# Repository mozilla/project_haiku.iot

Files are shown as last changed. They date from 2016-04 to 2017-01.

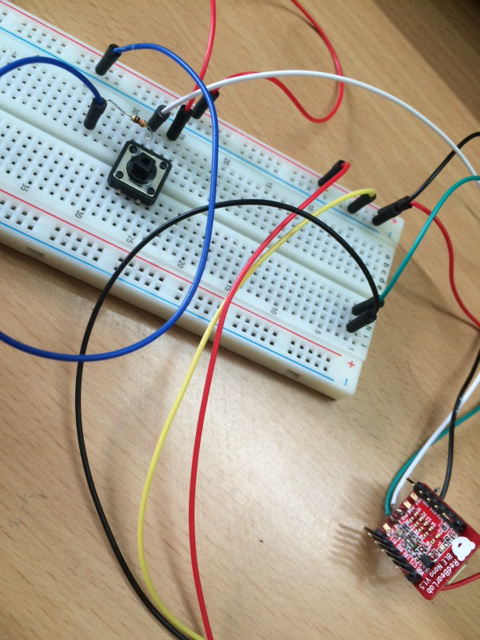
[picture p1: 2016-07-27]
Bluetooth/nRF51822/Arduino/Assets/images/BLE-Peripheral-NeoPixel-Nano-Circuit-2.JPG

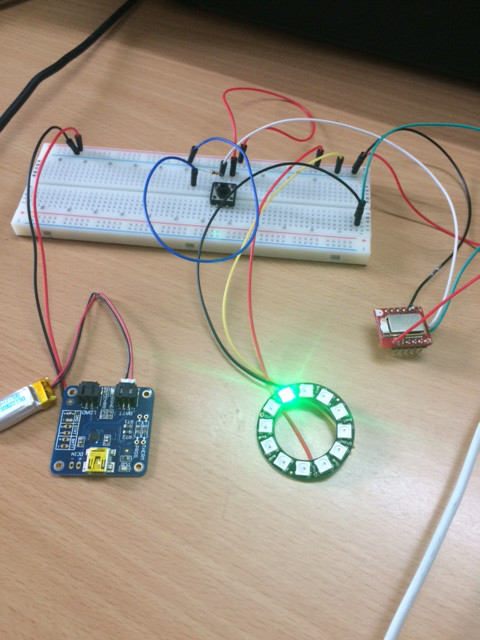
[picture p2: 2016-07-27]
Bluetooth/nRF51822/Arduino/Assets/images/BLE-Peripheral-NeoPixel-Nano-Circuit-3.JPG

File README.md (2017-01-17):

# Mozilla Project Haiku

### &#x1F534; Project Status - On Hold

Learn about the Project Haiku (former Project Smart Home) on the Mozilla wiki
* [https://wiki.mozilla.org/Connected_Devices/Projects/Project_Haiku](https://wiki.mozilla.org/Connected_Devices/Projects/Project_Haiku)

Follow our progress in our Github wiki
* [https://github.com/mozilla/project_haiku.iot/wiki](https://github.com/mozilla/project_haiku.iot/wiki)
* Github won't notify you when this wiki is updated, but you can [subscribe via RSS](https://github.com/mozilla/project_haiku.iot/wiki.atom).

Links to related repos
* The status API service used by Project Haiku and its experiments    
https://github.com/mozilla/project_haiku_status_api.iot    
* Reports and visualizations of data collected from Project Haiku user studies    
https://github.com/mozilla/project_haiku_dataviz.iot    
* Signalling server to connect pairs of WebRTC clients
https://github.com/mozilla/project_haiku_webrtc_signaling.iot

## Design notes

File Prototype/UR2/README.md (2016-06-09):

# smarthome.iot / User Research #2 Prototype

This prototype will support of our next round of user research, in which we are investigating 1:1 communication with a simple physical device, built around the Particle "Photon" board.

> This prototype was built for a specific purpose - to test a hypothesis and prompt feedback to help refine and steer development of products from Project Haiku. Please [contact the team](https://wiki.mozilla.org/Connected_Devices/Projects/Project_Haiku#Getting_in_touch) if you have suggestions or questions, or encounter problems building it.

### Overview

The device connects over Wifi to Particle's cloud service where "messages" are exchanged between an identical "paired" device held by a friend. The device has a single button, and clicking/double-clicking/long-clicking on one results in a different LED animation on the other.

### Bill of Materials

Vendor links are just a suggestion. You may want to adjust based on what you can get hold of locally, quantity etc. Our code is currently specific to the Photon board (but could be ported to other similar platforms.)

* Particle Photon *without headers* [Particle store](https://store.particle.io/)
* USB LiIon/LiPoly charger - [Adafruit](https://www.adafruit.com/products/259)
* "Neopixel" WS2812 addressable LED strip. Non-waterproof, 60 LEDs per meter. (cut strip of 5 LEDs per unit) [Amazon](http://www.amazon.com/Mokungit-Programmable-Individually-Addressable-Non-waterproof/dp/B01D1EDDR8)
* 3.7v 2000mAh Lithium Ion Battery [Adafruit](https://www.adafruit.com/products/2011) - note that shipping restrictions apply. Max 8 per order, no USPS delivery.
* 12x12x7mm Momentary Tactile Push Button Switch 4 Pin DIP [Amazon](http://www.amazon.com/uxcell%C2%AE-12x12x7mm-Momentary-Button-Switch/dp/B009ERT2NQ)
* 10K Ohm 1/4 watt resistor [Adafruit](https://www.adafruit.com/products/2784)
* 33K and 47k resistors for voltage divider [Adafruit](https://www.adafruit.com/products/2786), [Amazon](http://www.amazon.com/Projects-25EP51433K0-33k-Resistors-Pack/dp/B0185FCAUY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)  or [Amazon](http://www.amazon.com/Projects-EPC-106-Value-Resistor-Kit/dp/B00NENE5WY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)
* Pancake vibration motor [Adafruit](https://www.adafruit.com/products/1201)
* Mini USB Cable - A to Mini B [Amazon](http://www.amazon.com/StarTech-com-Mini-USB-Cable-USB2HABM6RA/dp/B004NO0L4O)
* Ribbon wire for all the connections. E.g. [Sparkfun](https://www.sparkfun.com/products/10646)
* Strip Board [Amazon](https://www.amazon.com/gp/product/B0076O73HQ/ref=oh_aui_detailpage_o00_s00?ie=UTF8&psc=1)

Tools
* Soldering Iron [Amazon](https://www.amazon.com/gp/product/B013JM4AW4/ref=oh_aui_detailpage_o08_s01?ie=UTF8&psc=1), Lead Solder [Sparkfun](https://www.sparkfun.com/products/9161) [Optional  [metal stand](https://www.sparkfun.com/products/9477) , [helping hand](http://www.amazon.com/SE-MZ101B-Helping-Magnifying-Glass/dp/B000RB38X8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) ]
* Wire Stripper [Sparkfun](https://www.sparkfun.com/products/12630) , Flush Cutters [Sparkfun](https://www.sparkfun.com/products/11952)
* Hot Glue gun or permanent glue to stick plastic parts
* Enclosure 3d Printed using 3d printer or using vendors such as Shapeways

### Building the Prototype Device

#### 3D Printing the enclosure

The OpenSCAD source file and print-ready [enclosure.stl](assets/3d/enclosure.stl) are in the [Prototype/assets/3d](assets/3d) directory. We used white ABS with a normal "regular quality" print profile: 0.25mm layer height, 1mm shell, no brim or other supports.

#### Assembling the Electronics

Most parts are off the shelf. If creating the device on the breadboard you can simply wire it up with jumper wires. To fit into the enclosure, you will need to cut down a piece of strip board to 6 columns and ~14 rows. The videos below walk through wiring it all up and getting it into the enclosure.

* [Wiring diagram](assets/BlinkyButton_bb.png)
* [Walkthrough video 1/3](https://www.youtube.com/watch?v=C2MHg81-BwQ) - First stage of assembling the device, wiring up the Particle Photon board and the LiPo charging board2.
* [Walkthrough video 2/3](https://youtu.be/lktK18RHnlE) - Completing wiring
* [Walkthrough video 3/3](https://youtu.be/VAnI2gIuZO8) - Packing the enclosure

#### Software

##### Setup Your Photon

* To use Photon board, you need to setup your Photon. Particle provides plenty of options for registering your Photons with your local WiFi.  Recommended way to setup your photon is via [Particle Mobile App](https://docs.particle.io/guide/getting-started/start/photon/#prerequisites-for-setup), you'll have to create a particle account in order to manage your particle boards.
* If you prefer command line tools, you'll need to have [node.js](https://nodejs.org/) and [particle-cli](https://github.com/spark/particle-cli) installed on your computer.
* Follow the [quickstart instruction](https://docs.particle.io/guide/getting-started/start/photon/#step-1-power-on-your-device) on photon website to create an particle account, connect your photon to wifi, and claim it under your account.
* Please note both the devices in a pair should be claimed under the same particle account.

##### Configure

* Go to https://build.particle.io, and click on Create New App and name it e.g. ‘buzzy-pixel’ and hit save icon on left. This should create a new file buzzy-pixel.ino.
* Click on Libraries button, and find BlingButton in Community Libraries. Select BlingButton library, and click on Include In App.
* Go back to your created app ‘buzzy-pixel’, and paste following code inside the buzzy-pixel.ino file.
https://github.com/mozilla/project_haiku.iot/blob/master/Prototype/InternetButton/buzzy-pixel/buzzy-pixel.ino

Note: For accessing included BlingButton library, change include reference in above buzzy-pixel.ino code from "BlingButton.h" -> "BlingButton/BlingButton.h",  "Page.h" -> "BlingButton/Page.h"

* Add new file by clicking on ‘+’ on top right. Rename the file as ‘ButtonConfig.h’ [You can delete the corresponding cpp file created by default]
* Paste the below config settings code in ButtonConfig.h
https://github.com/mozilla/project_haiku.iot/blob/master/Prototype/InternetButton/buzzy-pixel/ButtonConfig.h

###### Understanding ButtonConfig

ButtonConfig file settings are used to identify Device 1 and Device 2 in a pair.
* For Device 1  PUBLISH_EVENT_NAME  should be set as "DEVICE_1_BUTTON_PRESS" and SUBSCRIBE_EVENT_NAME should be "DEVICE_2_BUTTON_PRESS".
* For Device 2 in a pair PUBLISH_EVENT_NAME  should be set as "DEVICE_2_BUTTON_PRESS" and SUBSCRIBE_EVENT_NAME should be set as "DEVICE_1_BUTTON_PRESS.
* BATTERY_CHECK flag in config file is used to trigger [battery level check code](https://github.com/mozilla/smarthome.iot/blob/master/Prototype/InternetButton/buzzy-pixel/buzzy-pixel.ino#L116) . It ensures device goes to sleep if battery level is below the BATTERY_THRESHOLD.
* BATTERY_CHECK_TIME flag sets the time interval after which you want to repeat battery level check.

##### Flash code

Make sure both your photon devices are connected and breathing cyan.  By default ButtonConfig is set for Device1, follow below steps to flash Device 1 in a pair.

* Click on Devices button in https://build.particle.io, and star the device you want to flash.
* Click Verify button, It should compile code in the cloud and you should get code verified message on bottom left
* Click Flash button, if it's blinking purple, and reboot to breathing cyan after a while, it should be working properly.

Update ButtonConfig.h (See Understanding ButtonConfig) for Device 2 and repeat above three steps. After flashing, devices should be communicating and sending ambient messages to paired device.

##### Alternative: Flash with Command Line Tools

Login particle with your email and password if you haven't using command

* particle login.

Make sure you cd into the Prototype/InternetButton/buzzy-pixel directory, change the ButtonConfig.h in Prototype/InternetButton/buzzy-pixel/ButtonConfig.h and flash code with following command:

* particle flash {your_photon_name} ./*

If it's blinking purple, and reboot to breathing cyan after a while, it should be working. Change the ButtonConfig.h for Device 2 settings and flash Device 2.

[Link to End to End instructions >>](https://drive.google.com/a/mozilla.com/file/d/0ByJ_mHuB-es3ckNXVHVpNDFPTUU/view)

### Operating Instructions

#### Connecting to WiFi network

After device is flashed with buzzy-pixel code, you can connect to a different WiFi network (without captive portal) using below steps.

* Make sure your WiFi is turned on. If phone: Tap Home > Settings > WiFi on your phone. If computer: do tap WiFi icon on your computer to choose a WiFi network.
* Press SETUP button on your device for 3 seconds. This will put your device in Listening Mode and your device should begin blinking dark blue. When your device is in Listening Mode, it is waiting for you to connect it to WiFi.
* Go to Home > Settings > Wifi and change to the Photon-XXXX network.
* After connected to Photon-XXXX network, open browser and enter this URL http://192.168.0.1/index.html in a browser window.
* Click the Scan button. A list of WiFi networks will show.
* Press the option button for your home WiFi network.
* Enter your home WiFi password in the Password field. Then click Connect button. Your device should blink green to let you know it’s trying to connect to the internet. An alert will show with help instruction in case you entered wrong password. Press OK.
* Give your device a few seconds to connect and start blinking light blue. When it is blinking light blue, your device is happily connected to the Internet!

#### Reset to remove stored WiFi data from device
To wipe any stored WiFi credentials on the device, hold the MODE button for about ten seconds, until the RGB LED blinks blue rapidly.

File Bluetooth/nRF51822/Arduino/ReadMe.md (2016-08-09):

# Bluetooth Low Energy (BLE) technology

Arduino sketches to flash on RedBear Labs nRF51822 or BLE Nano board. Install Lightblue iOS app or the Android App - B-BLE to scan and debug BLE peripheral devices

## Steps to run BLE_UART_LED

* Follow Get Started steps using link below and Install latest 1.0.6 RedBearLabs nRF51822 board using board manager: https://github.com/RedBearLab/nRF51822-Arduino#install-board-package-add-on

* To upload the code on BLE Nano or nRF51822 dev board there are two options
* Option 1: Use Arduino IDE to compile and upload the code on the respective boards

* Option 2: The bootloader allows you to load firmware Over-the-air, for example, if you do not have the MK20 USB interface dongle.
 https://github.com/RedBearLab/nRF51822-Arduino#ota

a) Export Compiled library using Menu -> Sketch -> Export Compiled Binary

b) Install Nordic "nRF Toolbox” App on your smart phone and use it to open compiled library sent to your phone using air drop. Select file type "application" and select a device (you should see DFU_S130_V1.0 or RGB [device local name set in the sketch] in the device list) , On iOS, select firmware by navigating to User -> Inbox -> select firmware hex file and than click Upload

c) The firmware should upload and should show progress bar of file getting uploaded with the success message if file uploads successfully.

* To run BLE_UART_LED, use LightBlue app to find BLE Nano peripheral ‘RGB’ and select to connect. It should show two services click on write. Select Write new value and enter ‘000000’ for turning LED off. Enter ‘010203’ or any number other than 0 to turn LED on. The lED is attached to pin 13, on BLE Nano its next to 'RedBearLab' text on the board.  You can see the output in serial monitor at baud rate 9600.  

### Arduino Upload Instructions if nothing else work:
For uploading Arduino sketches your board should be preloaded with boot loader.hex. Ideally the above steps should work without explicit manual copy of the bootloader.hex.

In case you are getting error uploading Arduino file on the board, you can try copying bootloader.hex to /MBED
https://github.com/RedBearLab/nRF51822-Arduino#burn-bootloader

For Mac, I had to copy using Terminal  cp -vX bootloader.hex /Volumes/MBED/

## Steps to run BLE-Peripheral-SPI-LED

* Install 1.0.5 RedBearLabs nRF51822 board using board manager: https://github.com/RedBearLab/nRF51822-Arduino#install-board-package-add-on . There is an issue because of which code doesn't compile using latest 1.0.6 board. See https://github.com/sandeepmistry/arduino-BLEPeripheral/issues/70

* Open BLE-Peripheral-SPI-LED.ino file and upload the code to the respective board

* To run  BLE-Peripheral-SPI-LED, use LightBlue app to find BLE Nano peripheral ‘Arduino’ or 'LED' and select to connect. It should show one READWRITE service. Select Write new value and enter ‘00’ for turning LED off. Enter ‘01’ or any number other than 00 to turn LED on. You can see the output in serial monitor at baud rate 9600.  

### OTA Application upload

* Click Sketch -> Export Compiled Library. This will compile and create hex file in the same folder as respective ino file

* Send the hex file using Airdrop to SmartPhone and use nRFToolBox app to open the hex file

* Select the file in the app and the device to upload file to. Press reset button on the board and click upload in the app. Everytime, if you reset the board by hitting the button on the board, the bootloader will broacast the OTA service via BLE for 5 sec waiting for a connection to be made. Otherwise, it will start the pre-loaded firmware.

[Link to Video](http://youtu.be/w5vUd6isJYQ) to update RBL nRF51822 OTA and and run BLE-Peripheral-SPI-LED

## Steps to run BLE-Peripheral-NeoPixel

* Install 1.0.5 RedBearLabs nRF51822 board using board manager: https://github.com/RedBearLab/nRF51822-Arduino#install-board-package-add-on.

* Go to Sketch -> Include Library -> Manage Libraries. Search for Adafruit NeoPixel and install latest version 1.0.5. Installed library needs nRF51 board support to compile.
See https://github.com/adafruit/Adafruit_NeoPixel/pull/42

* Overwrite Adafruit_NeoPixel.cpp inside installed libraries at /Documents/Arduino/libraries/Adafruit_NeoPixel/ with [nRF51 Adafruit_Neopixel.cpp](https://github.com/mozilla/project_haiku.iot/tree/master/Bluetooth/nRF51822/Libraries/Adafruit_NeoPixel_nRF51/) file from here.

* Open BLE-Peripheral-NeoPixel.ino file and upload the code to the respective board.

* To run  BLE-Peripheral-SPI-LED, use LightBlue app to find BLE Nano peripheral device ‘Arduino’  and select to connect. It should show  READ-WRITE and  READ-NOTIFY services. Select READ-WRITE service and click on Write new value and enter ‘00’ for turning NeoPixel off. Enter ‘01’ or any number other than 00 to turn NeoPixel on. You can see the output in serial monitor at baud rate 9600.  Click on READ-NOTIFY service and start listening to notifications. Button press should send 0x01 and turn NeoPixel on. Release of button should send 0x00 and turn NeoPixel off.

[Link to Video](http://youtu.be/LVIa5FvAGQE) to run BLE-Peripheral-NeoPixel on BLE Nano

### Bill Of Material - BLE-Peripheral-NeoPixel

*  BLE Nano & MK20 USB Board - http://redbearlab.com/blenano/
* [Optional] RedBearLab nRF51822 Pinout - http://redbearlab.com/redbearlab-nrf51822/ (Ideally BLE Nano should suffice, for beginners nRF51822 dev board is recommended instead of BLENano at first as it has easy pin out interface)
* "Neopixel" WS2812 addressable LED strip. Non-waterproof, 60 LEDs per meter. (cut strip of 5 LEDs per unit) [Amazon](https://www.amazon.com/Mokungit-Programmable-Individually-Addressable-Non-waterproof/dp/B01D1EDDR8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)
* Sparkfun inventor kits part for resistor, buttons, led and jumper wires - [Sparkfun](https://www.sparkfun.com/products/13110)
* Breadboard - [Sparkfun](https://www.sparkfun.com/products/12002)

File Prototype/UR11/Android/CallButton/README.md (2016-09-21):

# Project Haiku - UR #11

#### Android Call Button app

A simple app that let user call a pre-configured contact on click of button. To simplify testing enter the phone number in the text box provided and click Call. 

Call Button app supports Android 5.0 and above. Tested install with Android Studio 2.1.3

Useful link
* [Creating Android App](https://developer.android.com/training/basics/firstapp/creating-project.html)
* [Requesting permission in Android 6.0 (API level 23 and above)](https://developer.android.com/training/permissions/requesting.html)

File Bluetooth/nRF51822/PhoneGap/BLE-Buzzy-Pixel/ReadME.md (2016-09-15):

# Cordova Android app BluetoothLE Buzzy Pixel

Cordova app communicating with NeoPixel using BLE

## Steps to run BluetoothLE Buzzy Pixel Android app

Follow below commands to create cordova Android app. [Link with command details](https://cordova.apache.org/docs/en/latest/guide/cli/)

* sudo npm install -g cordova
* install android studio which brings in android sdk http://developer.android.com/sdk/installing/index.html?pkg=studio

* cd BLE-Buzzy-Pixel/
* cordova platform add android
* To check if you satisfy requirements for building the platform use command - cordova requirements
* cordova plugin add cordova-plugin-bluetoothle@3.1.0 - [Tested with 3.1.0]
* cordova plugin add path to local cordova-plugin-fetch directory [../Plugins/cordove-plugin-fetch]
* Update [config settings here](https://github.com/mozilla/project_haiku.iot/blob/master/Bluetooth/nRF51822/PhoneGap/BLE-Buzzy-Pixel/www/js/config.js). Read below for more details about variables defined inside config.js.
* Status Service is link to cloud service to read and update status and messages. If you have the URL to cloud service, update config or read below for starting status API service on your local machine.
* cordova build
* connect android device to your machine, then to run app use command- cordova run android

## Config.js
* selfLED is the neopixel assigned to display status of the  BLE device. This value should be same as SELF_LED defined in the [BLENano sketch config](https://github.com/mozilla/project_haiku.iot/blob/master/Bluetooth/nRF51822/Arduino/BLE-Buzzy-Pixel/config.h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)
* baseURL is the address where cloudservice is running
* selfURL is the path '/user/[selfLED]/status' to get client status from cloud service
* ledLength is number of leds on the BLE device
* statusItems is array of relative path to retrieve status of all leds on the BLE device

## Status API Service
* To run status API service on your local, get code from repo https://github.com/mozilla/project_haiku_status_api.iot/tree/exp4-noslots
* Run npm start to start service at port 3000
* Open test client http://localhost:3000/example.html to view and change client 0 status. Click on start button to start polling. Click on first LED toggles status from 1 to 0 (green to red).

## Useful links
* https://cordova.apache.org/docs/en/latest/guide/cli/
* https://github.com/randdusing/cordova-plugin-bluetoothle
* https://www.uuidgenerator.net/
* To remove a plugin cordova plugin remove <plugin-name>
* To view plugin installed - cordova plugin list

## Android version < 6.0

cordova-plugin-bluetoothle 3.1.0 and above needs Andoid API > 23 that comes with Android 6.0 and above.

For version below Android 6, App need to support cordova-plugin-bluetoothle version 2.4.0 or below - TBD

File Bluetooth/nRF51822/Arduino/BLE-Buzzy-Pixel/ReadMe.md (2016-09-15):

# Bluetooth Low Energy (BLE) Buzzy Pixel

BLE Buzzy Pixel Arduino sketch to read and set status and animations on NeoPixel strip

## Steps to run BLE-Buzzy-Pixel

* Install 1.0.5 RedBearLabs nRF51822 board using board manager: https://github.com/RedBearLab/nRF51822-Arduino#install-board-package-add-on.

* Go to Sketch -> Include Library -> Manage Libraries. Search for BLE Peripheral and install version 0.2.0

* Search for Adafruit NeoPixel library and install version 1.0.5. Installed library needs nRF51 board support to compile.
See https://github.com/adafruit/Adafruit_NeoPixel/pull/42

* Overwrite Adafruit_NeoPixel.cpp inside installed libraries at /Documents/Arduino/libraries/Adafruit_NeoPixel/ with [nRF51 Adafruit_Neopixel.cpp](https://github.com/mozilla/project_haiku.iot/tree/master/Bluetooth/nRF51822/Libraries/Adafruit_NeoPixel_nRF51/) file from here.

* Open BLE-Buzzy-Pixel.ino file. Update config.h with pin out and pixel count settings as per your circuit and upload the code to BLE Nano.

* If there are erros while uploading sketch using Arduino IDE, follow [instrcutions here](https://github.com/mozilla/project_haiku.iot/tree/master/Bluetooth/nRF51822/Arduino/Examples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) to copy latest bootloader.hex to BLE Nano board. 

* To test uploadeded sketch BLE-Buzzy-Pixel, use LightBlue iOS app or nRFCOnnect Android app to find BLE Nano peripheral device 'BLE-Buzzy-Pixel'  and select to connect. It should show  READ-WRITE and  READ-NOTIFY services. Select READ-WRITE service and click on Write new value and enter ‘00’ for turning NeoPixel off. Enter ‘01’ to turn NeoPixel on. You can see the output in serial monitor at baud rate 9600.
Click on READ-NOTIFY service and start listening to notifications. Button press should send 0x01 and turn NeoPixel on. Release of button should send 0x00 and turn NeoPixel off.

* To test uploaded sketch with BLE-Buzzy-Pixel Cordova app, install app on Android phone following [instructions here](https://github.com/mozilla/project_haiku.iot/tree/master/Bluetooth/nRF51822/PhoneGap/BLE-Buzzy-Pixel)

[Link to Video](http://youtu.be/B1qS--DboT4) showing BLE-Buzzy-Pixel Cordova app communicating with BLE Nano

### Bill Of Material - BLE-Buzzy-Pixel

*  BLE Nano & MK20 USB Board - http://redbearlab.com/blenano/
* [Optional] RedBearLab nRF51822 Pinout - http://redbearlab.com/redbearlab-nrf51822/ (Ideally BLE Nano should suffice, for beginners nRF51822 dev board is recommended instead of BLENano at first as it has easy pin out interface)
* "Neopixel" WS2812 addressable LED strip. Non-waterproof, 60 LEDs per meter. (cut strip of 5 LEDs per unit) [Amazon](https://www.amazon.com/Mokungit-Programmable-Individually-Addressable-Non-waterproof/dp/B01D1EDDR8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)
* Sparkfun inventor kits part for resistor, buttons, led and jumper wires - [Sparkfun](https://www.sparkfun.com/products/13110)
* Breadboard - [Sparkfun](https://www.sparkfun.com/products/12002)

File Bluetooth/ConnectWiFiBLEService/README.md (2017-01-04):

BLE server that broadcasts WiFi connect service on ARM linux device (BeagleBoneGreen Wireless).
Device can be configured and connect to WiFi by passing WiFi credential
using client app such as nRFConnect (Android).

## Setup BBGW

* [Follow steps](https://github.com/mozilla/project_haiku.iot/wiki/Boot--BeagleBone-Black-via-microSD-Card) to boot BBGW via microSD Card.
Used latest debian image bone-debian-8.6-lxqt-4gb-armhf-2016-11-06-4gb.img.xz 

* Connect BBGW to wifi using connmanctl, type connmanctl.

* First turn tethering off for wifi! 

    _connmanctl> tether wifi off_

    _Disabled tethering for wifi_

* You can then perform the rest of the connmanctl actions to set wifi:

    _connmanctl> scan wifi_

    _Scan completed for wifi_

    _connmanctl> services_

    _TEST wifi_deadbeef0000_4b41595a4545505550_managed_psk_

    _connmanctl> agent on_

    _Agent registered_

    _connmanctl> connect wifi_deadbeef0000_4b41595a4545505550_managed_psk_

    _Agent RequestInput wifi_deadbeef0000_4b41595a4545505550_managed_psk_

    _Passphrase = [ Type=psk, Requirement=mandatory, Alternates=[WPS ] ]_

    _WPS = [ Type=wpspin, Requirement=alternate ]_

    _Passphrase? WTGD3g3gk69lw_

    _Connected wifi_deadbeef0000_4b41595a4545505550_managed_psk_

    _connmanctl> quit_

* Once its connected to WiFi, install and update packages. This takes 15-30 minutes

    _sudo apt-get update_

    _sudo apt-get dist-upgrade_

* Update node to latest version using below commands

    _curl -sL https://deb.nodesource.com/setup_7.x | sudo -E bash -_

    _sudo apt-get install -y nodejs_

## To run [bleno module](https://github.com/sandeepmistry/bleno) on debian

* Install all prerequisite from bleno github page for debian

    _sudo apt-get install bluetooth bluez libbluetooth-dev libudev-dev_

* Run _sudo bb-wl18xx-bluetooth_

    This is built-in script for wireless-capable BeagleBone models
that discovers Bluetooth hardware and sets it up for use.

* Verify if bluetoothhd is running using command

    _pgrep bluetoothd_

    If yes disable the process by using below commands as it
interferes with the [bluetooth process](https://github.com/sandeepmistry/bleno#linux). /user/lib/bluetooth/bluetoothhd deamon shouldn’t appear in process list

    _ps -ef | grep blue_

    _sudo kill -9 <pid>_

## Disconnect WiFi 
* If BBGW is previously connected to WiFi, one can remove stored network name and passphrase by editing file  /var/lib/connman/*/settings
* Reboot BBGW to disconnect from previously connected WiFi

## Run ConnectWiFi BLEService

    npm install

    npm install async@0.6.0 // To fix async.retry error thrown by connman-simplified node package

    node connect.js

## Bluetooth logs using hcidump

    sudo apt-get install bluez-hcidump

    sudo hcidump -t -x

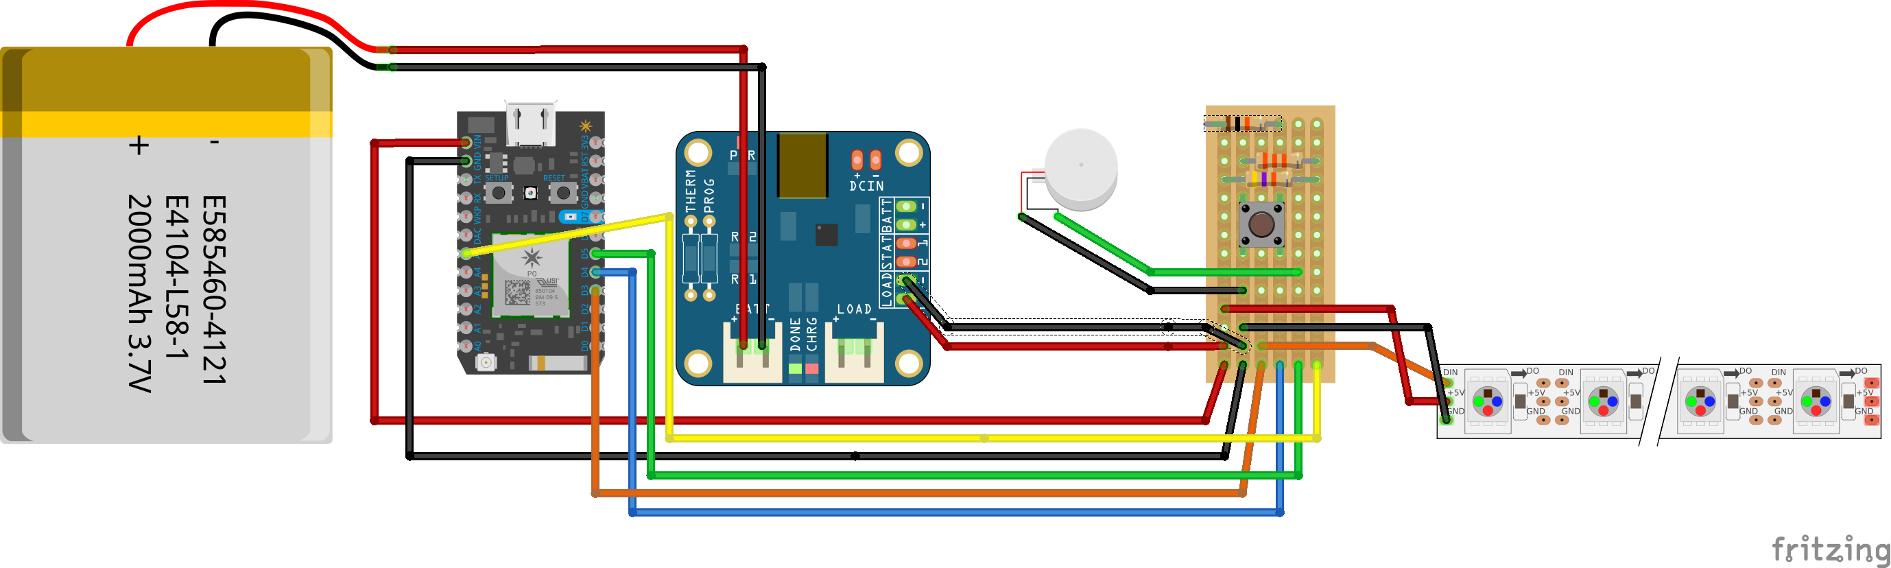
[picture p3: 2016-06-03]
Prototype/UR2/assets/BlinkyButton_bb.png

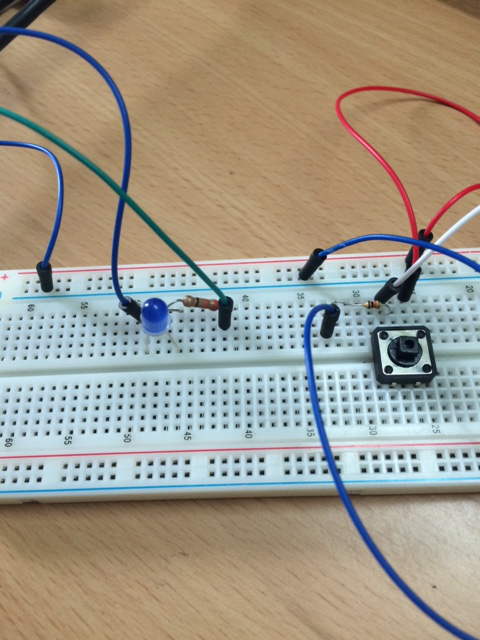
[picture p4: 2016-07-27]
Bluetooth/nRF51822/Arduino/Assets/images/BLE-Peripheral-SPI-LED-Circuit.JPG

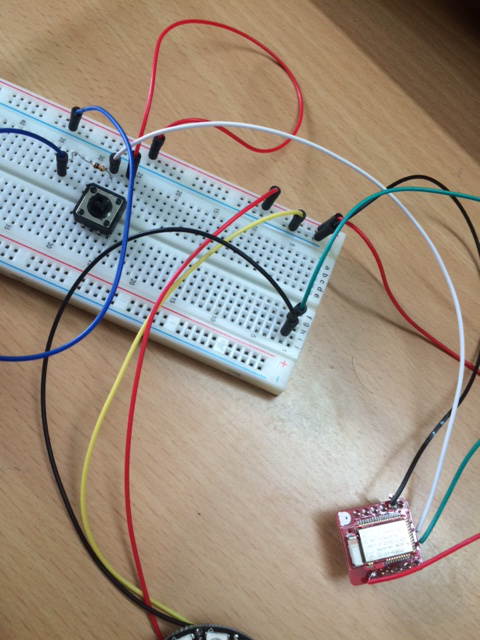
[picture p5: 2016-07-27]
Bluetooth/nRF51822/Arduino/Assets/images/BLE-Peripheral-NeoPixel-Nano-Circuit-1.JPG

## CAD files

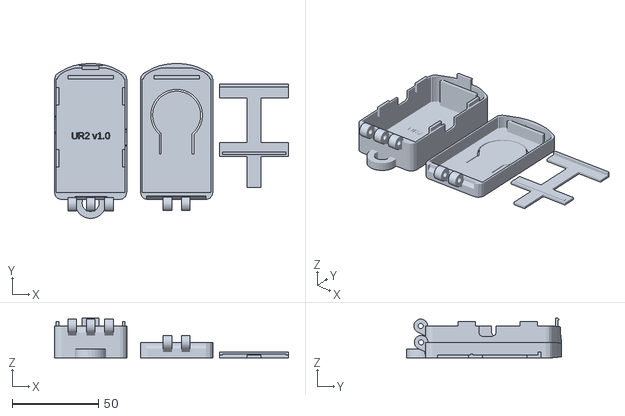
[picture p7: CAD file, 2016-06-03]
Prototype/UR2/assets/3d/enclosure.stl
136.0 x 90.0 x 23.0

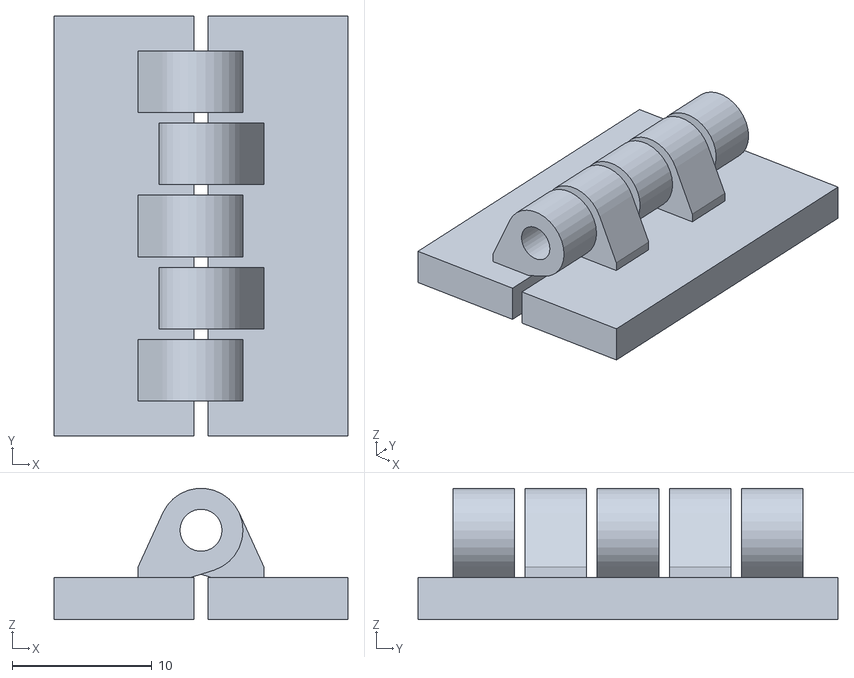
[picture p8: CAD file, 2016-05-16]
Prototype/UR2/assets/3d/test-hinge.stl
21.0 x 30.0 x 9.36

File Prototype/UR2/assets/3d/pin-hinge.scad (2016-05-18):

module example_hinge() {
    translate([0,0,6]) {
        horizontal_pin_with_5_fingers(25, 3);
        translate([5.5,0,-0.5*(6+2.25)]) #cube([10, 30, 3], center=true);
        translate([-5.5,0,-0.5*(6+2.25)]) cube([10, 30, 3], center=true);
    }
}

function debugprint(s) = search(s, []);

module chamfered_cube(dims, chamfer, center=true) {
    w=dims[0]; l=dims[1]; h=dims[2];
    linear_extrude(height=h,twist=0,center=center) {
        offset(r=chamfer) {
          square([w-chamfer*2,l-chamfer*2], center=center);
        }
    }
}

module countersink_ends(h, radius, pin_radius) {
    union() {
        chamfer = pin_radius*1.5;
        // chamfer the pin hole at each end
        translate([0,0,pin_radius/2]) #cylinder(r1=chamfer, r2=pin_radius, h=pin_radius, center=true);
        translate([0,0,h-pin_radius/2]) #cylinder(r1=pin_radius, r2=chamfer, h=pin_radius, center=true);
    }
}

module pin_hinge_unit(h, radius, pin_radius=1.5, index=0, gap=0.5) {
    $fn=30;
    translate([0,radius-gap,0]) difference() {
        // the barrel+lug
        hull() {
            cylinder(r=radius, h=h, center=true);
            translate([index%2>0 ? radius*0.875 : radius*-0.875, radius/2+gap*2, 0]) {
                cube([radius+gap,gap,h], center=true);
            }
        }
        // the hole for the pin
        #cylinder(r=pin_radius, h=h, center=true);
    }
}


module pin_hinge(h, radius, fingers=3, pin_radius=1.5, gap=0.5) {
    total_gap=(fingers-1)*gap;
    unit_h=(h-total_gap)/fingers;
    translate([0,0,unit_h/2]) union() {
        for(i=[0:fingers-1]) {
            translate([0,0, gap*i+i*unit_h]) pin_hinge_unit(unit_h, radius, pin_radius, i);
        }
    }
}

module horizontal_pin_with_5_fingers(length, radius=3, pin_r=1) {
    translate([0,-length/2,3]) rotate([-90,0,0]) pin_hinge(length, radius, 5);
}

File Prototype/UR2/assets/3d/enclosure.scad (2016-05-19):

use <pin-hinge.scad>;
model_version="UR2 v1.0";
width=40;
half_w=width/2;
length=66;
half_l=length/2;
height=17.5;
lid_height=8;
wall=1;
radius_xy=wall*4;
radius_z=wall*2;
inset=0.75;
strap_height=13;

// debug: check all objects sit on the bed platform
//projection(cut=true) {
translate([width/3,0,-1]) %cube([width*4, length+20, 2], center=true);
union() {
    offset_x=5;
    enclosure_base([-1*(width/2+offset_x),0,height/2+wall/2]);
    enclosure_lid([width/2+offset_x,0,lid_height/2+wall/2]);
    enclosure_straps([width+offset_x*2+20,0,0.75]);
}
//}

// the base
module enclosure_base(offsets) {
    translate(offsets) {
        difference() {
            union() {
                hinged_box(width, length, height, 1);
                // lanyard attach point
                translate([0,-0.5*length-6, -0.5*(height+wall)+2.5]) {
                    difference() {
                        cylinder(r=9, h=5, center=true);
                        union() {
                            cylinder(r=5, h=5, center=true);
                            translate([0, 8.5, 0]) cube([18, 5, 5], center=true);
                        }
                    }
                }
                // lip
                union() {
                    lip_w=wall*1.5;
                    lip_h=6;
                    translate([half_w-lip_w/2,-half_l+20,wall+height/2-1]) cube([lip_w, 10, lip_h], center=true);
                    translate([-half_w+lip_w/2,-half_l+20,wall+height/2-1]) cube([lip_w, 10, lip_h], [0,2,0], center=true);
                    translate([half_w-lip_w/2,-half_l+56,wall+height/2-1]) cube([lip_w, 10, lip_h], center=true);
                    translate([-half_w+lip_w/2,-half_l+56,wall+height/2-1]) cube([lip_w, 10, lip_h], center=true);
                }
            }
            union() {
                // version stamp
                translate([0,0,-height/2+wall-0/0.25]) {
                    #linear_extrude(height=1, center=true)
                        text(model_version, size=4, valign="center", halign="center");
                }
                
                // aperture for the usb port
                translate([-width/2-wall, -length/2+39.5, height/2-1]) {
                   rotate(90) charge_port(10, 7, wall*2);
                }
                *translate([width/2+wall-1, -length/2+32, height/2-5]) {
                   #cube(5);
                }
                // aperture for the battery port
                translate([width/2+wall-1, -length/2+32, height/2-1]) {
                   rotate(90) #charge_port(10, 7, wall*2);
                }
                // latch push
                translate([0, length/2+width/4-1.25, width/4-2]) rotate([90,0,0]) #cylinder(r=7, h=inset*2, center=true);
            }
        }
    }
}

// the lid
module enclosure_lid(offsets) {
    translate(offsets) rotate([0,180,0]) {
        difference() {
            union() {
                hinged_box(width, length, lid_height, -1);
            }
            #translate([0,12,lid_height/2]) rotate(180) button(10,36,wall*2);
        }

    }
}

module enclosure_straps(offsets) {
    // the strap
    length=60;
    translate(offsets) {
        union() {
            translate([0,0,0]) cube([8, length, 1.5], center=true);
            #translate([0,-length/2+20,0.75]) cube([width-3, 1.5, 1.5], center=true);
            translate([0,-length/2+22,0]) cube([width, 8, 1.5], center=true);
            translate([0,length/2-4,0]) cube([width, 8, 1.5], center=true);
            translate([0,length/2-0.75,1]) cube([width, 1.5, 3], center=true);
        }
    }
}

module retainer(dims, center=false) {
    xdim=dims[0];
    ydim=dims[1];
    zdim=dims[2];
    half_z=zdim/2;
    translate([0, 0, center? half_z/2 : 0]) {
        cube([xdim, ydim, half_z], center=center);
        translate([0,0,half_z]) {
            if (center) {
                cube([xdim-zdim*2, ydim, half_z], center=center);
            }
            else {
                translate([zdim, 0, half_z]) cube([xdim-zdim*2, ydim, half_z], center=center);
            }
        }
    }

}

module outer_ridges(radius, length, bounds) {
    translate([-1*(bounds[0]/2+radius/2), 0]) {
        rotate([180,0,0]) ridge(radius, length, 1);
    }
    translate([bounds[0]/2+radius/2, 0]) {
        rotate([180,0,0]) ridge(radius, length, -1);
    }
}
module ridge(radius, length, orient=1) {
    rotate([0,0,orient<0?0:180])
    translate([-radius/2, 0, radius/2]) difference() {
        rotate([90,0,0]) cylinder(r=radius, h=length, center=true, $fn=12);
        union() {
            translate([0,0,radius/2]) cube([radius*2, length, radius], center=true);
            translate([-radius/2,0,0]) cube([radius, length, radius*2], center=true);
        }
    }
}

module hinged_oval_box(width, length, height, orient) {
    // WIP/not in use
    hull() {
        translate([0, -length/2+5, 2]) {
            resize(newsize=[width, width/2, height]) sphere(d=width, center=true);
        }
        translate([0, +length/2-5, 2]) {
            resize(newsize=[width*1.25, width/2, height]) sphere(d=width, center=true);
        }
    }
}
module hinged_box(width, length, height, orient) {
    hinge_radius=4;
    hinge_y_offset=length/2+radius_xy+hinge_radius/2;
    difference() {
        union() {
            difference() {
                shell(width, length, height, orient);
                translate([0, -1*hinge_y_offset, orient*(height/2)]) {
                  rotate(a=[0,90,0]) translate([0,0,0.25]) {
                        // add clearance for opposite hinge barrels
                      #cylinder(r=hinge_radius,
                                h=width*.66+orient*-hinge_radius*2,
                                center=true);
                  }
                }

            }
            translate([0, -1*hinge_y_offset, orient*(height/2)]) {
              rotate(a=[90,180,0]) translate([0,0,0.25]) {
                  _pin_hinge(width*.66, hinge_radius, orient>0?0:1);
              }
            }
            // the latch
            translate([0,length/2+8.5,orient*(height/2-3)]) {
                translate([0,-1.5,0]) cube([20, wall, 6], center=true);
            }
            if (orient > 0) {
                translate([0,length/2+7.25,height/2+4.5]) {
                    translate([0,-1,-4.5]) cube([10, wall*1.5, 10], center=true);
                    rotate([90, 90, 0]) ridge(1, 10, 1);
                }
            }
        }
        union() {
            if (orient < 0) {
                // lid latch receiver
                translate([0,length/2+7.25,height/2-3]) {
                    difference() {
                        translate([0,0,-1.5]) #cube([10, wall*1.5, 2], center=true);
                        *translate([0,-1,-4.5]) cube([10, wall*1.5, 10], center=true);
                    }
                }
            }
        }
    }
}

module _pin_hinge(h, radius, is_top=0, clearance=0) {
    fingers=5;
    pin_radius=1.5;
    gap=0.25;
    total_gap=(fingers-1)*gap;
    unit_h=(h-total_gap)/fingers;
    rotate([-90,0,0]) rotate([0,90,0]) translate([0,-radius,-1*(h/2)+unit_h/2]) {
        for(i=[0:fingers-1]) {
            if (i%2>0 && is_top) {
                translate([-0.5,0, gap*i+i*unit_h]) {
                    pin_hinge_unit(unit_h, radius, pin_radius, i, gap);
                    translate([radius,radius*2,0]) cube([radius*1.5, radius, unit_h], center=true);
                }
            }
            if (i%2==0 && !is_top) {
                translate([0.5,0, gap*i+i*unit_h]) {
                    pin_hinge_unit(unit_h, radius, pin_radius, i);
                    translate([-1*(radius),radius*2,0]) cube([radius*1.5, radius, unit_h], center=true);
                }
            }
        }
    }
}
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

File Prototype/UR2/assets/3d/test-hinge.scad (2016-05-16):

use <pin-hinge.scad>;

example_hinge();

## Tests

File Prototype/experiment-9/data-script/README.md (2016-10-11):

Data Munging and Reports
========================

The raw data comes to use in PDF form from AT&T's account/billing page. The `scraperJSON.py` script turns those into usable JSON.

scraperJSON.py setup
--------------------

You'll need [pip](https://pypi.python.org/pypi/pip) to get the dependencies. If you don't already have pip:

```
sudo easy_install pip
```

then, in this directory (you may need to sudo if you arent using a virtualenv)

```
pip install PyPDF2
pip install python-dateutil
```

Generating JSON
---------------

The raw data from AT&T uses actual phone numbers - in the filename (this is the device in question - don't rename that file we need that) - and in the call/sms log. We map these to device IDs to anonymize and allow us to publish the JSON data files. `lookup.example.json` has an example of the format - copy this to `lookup.json` and populate it with the actual phone numbers and device IDs.

Then, to produce the JSON output:

```
python scraperJSON.py 'path/to/the/ATandT/download/999-999-9999_Data and Text Usage_10_3_2016_10_10_2016.pdf' > 999-999-9999.json
```

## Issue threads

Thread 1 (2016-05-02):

Develop a solution for reliable Wifi setup and clearly displaying connection status

sfoster, 2016-05-02:
We want an app-free (or app-optional) way to configure each device to connect to a WiFi network (entering SSID and password)

punamdahiya, 2016-05-05:
Issue #14 updated with instructions to connect to WiFi using browser

punamdahiya, 2016-05-13:
Feature is code complete and tested on few devices. Marking issue closed

Closed 2016-05-13.

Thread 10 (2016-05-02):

Battery power the device

punamdahiya, 2016-05-02:
Investigate hardware options to keep the device powered for 4-5 days
a) Using power shield to recharge LIPO battery
b) Device in sleep state when not connected to WiFi

sfoster, 2016-05-02:
I have a couple of battery mgmt and charging board getting shipped to me to work on this

sfoster, 2016-05-09:
In the Bill of Materials in the README (commit 5f06df7) I've included the Adafruit LiIon/LiPoly charger modules and a LiPoly 2000mAh battery. This lets us recharge the unit by plugging it into a USB wall adapter or computer etc. (The cable for USB-A to USB-MiniB is also in the BOM)

Initial testing shows the 2000mAh battery can power the device for 12+ hours, we'll need to do more testing when we've got more devices assembled and ready for use.

Note that we are simply wiring together the Photon to the charger module to the LiPoly battery itself. Each is an off-the-shelf component and my understanding is that we should inherit their guarantees and certifications for safety, compliance etc.

Closed 2016-05-09.

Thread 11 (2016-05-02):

Implement "click-hold" message LED animation

sfoster, 2016-05-02:
Write code to display a recognizable color/blink sequence when a "click and hold" message is received from the paired device

punamdahiya, 2016-05-16:
Feature is code complete and tested on few devices, closing the issue

Closed 2016-05-16.

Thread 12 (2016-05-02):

Investigate particle.io and secure communications

kglazko, 2016-05-02:
Ensure that our devices are able to communicate in a secure way. Particle.io uses oAuth to secure communications. We need to know if this is adequate, and how to ensure a device can only communicate with its paired device, and can only receive messages from that pair - to avoid deliberate or accidental miscommunication

punamdahiya, 2016-05-26:
Pairing is implemented by using separate accounts and using PRIVATE publish and subscribe.

Closed 2016-05-26.

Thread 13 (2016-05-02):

Solution for logging activity between 2 paired devices

sfoster, 2016-05-02:
Implement and/or document how we'll logging of activity between 2 paired widgets over the course of the study (or some time period). We may be able to use Particle's dashboard for this, or export data and create our own report format that displays the timeline

punamdahiya, 2016-05-04:
curl https://api.particle.io/v1/devices/events?access_token=<accesstoken> returns data in json format once the device is online

punamdahiya, 2016-05-04:
One option is to look into possibility of capturing and persisting json data with the spreadsheets available in Google Drive

kglazko, 2016-05-06:
Alright! Here goes my first implementation :)

##Web IDE and Code##

- Log into the ParticleIO Web IDE and upload your existing script. I am using a button flashing script.
- In my case, I created an event called LED with the following code: `Particle.publish("LED","on",16777215,PUBLIC);`
- You can create and publish as many events as you want, and name them anything that you want.

##Zapier##

- Head over to the Zapier website and create an account. Don't worry, it's very quick!
- Choose to make a zap that involves Webhooks and Google Drive.
- Follow the zap instructions, and when it comes to copy/pasting the Webhooks URL, copy the URL and continue to the next step

##Integration##

- Log into https://dashboard.particle.io and click on the 'Logs' icon. Make sure your particle shows up there.
- Click on the log. If the code is executing, you should see the events you created being displayed there. If not, make sure your code is running during the next step.
- Go to the Integrations tab and click on the Webhooks option. Name the event with the exact same way one of your events is named (case matters!), and paste in the webhooks URL from Zapier you got earlier. Save the webhook.

##Zapier, Cont'd.##

- After the copy/paste step, you will be asked to test the webhook. Do this, then continue through the instructions and save the Zap.
- Activate the zap.

##On your dashboard##

- You will be able to see POST requests being sent to the web hook in the Log section.

##On your Google Spreadsheet##

- You will be able to see the info that you designated to be sent during the Zapier set-up being sent to the spreadsheet. This can include JSON child info, etc.

kglazko, 2016-05-06:
All this coolness was sent via Webhooks :) https://docs.google.com/spreadsheets/d/1wWXVHtKRUui7LPdpyGS1LMUz9TQ-Mc5zG08bPvZhOdo/edit#gid=0

sfoster, 2016-05-26:
We have a solution here that is working for the UR#2. We'll revisit in a new issue for future improvements in further studies.

Closed 2016-05-26.

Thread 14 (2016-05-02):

Test and document instructions for connecting a device to WiFi network

punamdahiya, 2016-05-02:
Test and document instructions for connecting a device to WiFi network based on solution of Issue #1

punamdahiya, 2016-05-05:
Instruction to connect to WiFi

1. Press mode button on your device for 3 seconds. This will put your device in listening mode and your device should begin blinking blue. When your photon is in [Listening Mode](https://docs.particle.io/guide/getting-started/modes/core/#listening-mode), it is waiting for your input to connect to Wi-Fi. Image below shows the mode button on your device.
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

2. Tap Home -> Settings -> Wifi on your phone or tap WiFi icon on your computer to choose a WiFi network.
3. Make sure Wi-Fi is turned on and choose the network below , Photon -XXXX.
4. Once connected to access point Photon -XXXX, enter URL http://192.168.0.1/index.html in browser window
5. Click scan to find your Wifi network and enter password and click connect
6. Your device is blinking green, it is trying to connect to the internet. Give your device a few seconds to connect and start breathing cyan. When it is breathing cyan, your device is happily connected to the Internet.

punamdahiya, 2016-05-05:
Message on alert box after click of connect

Your device should now start flashing green and attempt to connect to the cloud. This usually takes about 20 seconds, after which it will begin slowly blinking cyan. If this process fails because you entered the wrong password, the device will flash green indefinitely. In this case, hold the setup button for 6 seconds until the device starts blinking blue again. Then reconnect to the WiFi access point 'Photon-XXXX' it generates and reload page  http://192.168.0.1/index.html to try again.

punamdahiya, 2016-05-06:
If device is not connecting to photon soft AP, following below steps seems to help
The only way to establish a connection is to.
1) Connect phone to another network or "forget" the Photon's network.
2) Press reset on the Photon.
3) Connect to the Photon's hotspot within a couple seconds.

This is a known issue https://github.com/spark/firmware/issues/692

punamdahiya, 2016-05-10:
Updated README with instrcutions https://github.com/mozilla/smarthome.iot/commit/6c0cfb467f00953264975429f3cf8017157a25d3

Detail instructions will be available in help guide issued to research participants https://docs.google.com/document/d/1rn0_VM6XXjWqJFVTPBveFsPKIMbEWMg_ZwO6hsDVXD8/edit#heading=h.bocyna5p8q0

Closed 2016-05-10.

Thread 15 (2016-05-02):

Implement pairing of 2 devices

sfoster, 2016-05-02:
We need a way for each device to listen for and publish events to a particular device which is its "pair". This can be done on the device e.g. some constant we populate in the code before flashing to the device, or the pairing could be done by the message "broker" which knows which device to relay messages to.

punamdahiya, 2016-05-06:
Another alternative to get 5 pairs ready is
1. Create a particle login [https://dashboard.particle.io/login] and claim the two buttons that should be paired under same login

2. This will ensure private publish and subscribe messaging between paired devices and their logs can be seen under single particle login

3. Flash Device 1 with code https://github.com/mozilla/smarthome.iot/tree/master/Prototype-UR2/InternetButton/buzzy-pixel

4. Update ButtonConfig.h by uncommenting line 14 and 15 and commenting line 8 and 9. Flash second device

Devices should be paired and communicate when connected to wifi network

punamdahiya, 2016-05-26:
We have pairing implemented and the details documented in user spreadsheet. Closing the issue.

Closed 2016-05-26.

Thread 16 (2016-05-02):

Investigate particle.io's capabilities - will it let us secure communications between devices?

sfoster, 2016-05-02:
Particle.io uses oAuth to secure communications. We need to know if this is adequate, and how to ensure a device can *only* communicate with its paired device, and can only receive messages from that pair - to avoid deliberate or accidental miscommunication

sfoster, 2016-05-02:
Dupe

Closed 2016-05-02.

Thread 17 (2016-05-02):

Create an enclosure for the device

sfoster, 2016-05-02:
We need some kind of enclosure to protect the circuit board from accidental damage, moisure etc. It needs to keep the LEDs visible, and the button(s) clickable, and provide access to the charging port.

sfoster, 2016-05-26:
We used openscad to model the enclosure, this file is at Prototype-UR2/assets/3d/enclosure.scad
This was 3d printed, using white ABS filament, 0.25mm layers, 1mm shell, no brim/supports, 25% fill (should be 50+%?)

Closed 2016-05-26.

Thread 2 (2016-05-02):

Send different signal on click, double-click and long click

sfoster, 2016-05-02:
We need logic on the device to resolve click/click frequency to one of 3 possible actions: "click", "double-click" and "click-and-hold" and call the appropriate function to send the corresponding request.

punamdahiya, 2016-05-13:
Feature is code complete and tested on few devices, closing the issue

Closed 2016-05-13.

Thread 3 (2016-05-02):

Respond to signals from paired device

sfoster, 2016-05-02:
When the device gets a message from its pair, we should call the appropriate function to acknowledge receipt and start playing the correct light animatoin

punamdahiya, 2016-05-13:
Feature is code complete and tested on few devices, closing the issue

Closed 2016-05-13.

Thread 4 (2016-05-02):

Implement "connecting" LED animation

sfoster, 2016-05-02:
Write code (or using existing code) to display a recognizable color/blink sequence to communicate to the user that the device is attempting to connect to a network

punamdahiya, 2016-05-06:
For the scope of this prototype we can leverage LED status available on photon. If photon is blinking green, it is trying to connect to the internet.
If Wi-Fi credentials are available to photon, in few seconds device connects and starts breathing cyan.

sfoster, 2016-05-09:
When we document wifi setup, lets add a note about the status LED. At that point we can consider this issue closed

punamdahiya, 2016-05-26:
Documented in help guide handed to research participants, closing the issue.

Closed 2016-05-26.

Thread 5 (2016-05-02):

Implement "paired" LED animation

sfoster, 2016-05-02:
Write code (or using existing code) to display a recognizable color/blink sequence to communicate to the user that the device is able to communicate with its paired device

punamdahiya, 2016-05-16:
Closing this issue as its scope is included in Issue #7

Closed 2016-05-16.

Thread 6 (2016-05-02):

Implement "not-connected" LED animatoin

sfoster, 2016-05-02:
Write code (or using existing code) to display a recognizable color/blink sequence to communicate to the user that the device is is not connected (or has failed to connect) to a network

punamdahiya, 2016-05-06:
For the scope of this prototype, we can use LED status on photon. If the device LED is color cyan , devices is connected to network.

sfoster, 2016-05-09:
When we document setup, lets make sure to add a note about the status LED. At that point we can consider this issue closed.

punamdahiya, 2016-05-26:
It is documented in the help guide handed to research participants. Closing the issue

Closed 2016-05-26.

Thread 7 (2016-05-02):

Implement "paired"/"not-paired" LED animations

sfoster, 2016-05-02:
Write code (or using existing code) to display a recognizable color/blink sequence to communicate to the user that the device is or is not able to communicate with its paired device.

punamdahiya, 2016-05-26:
For this study this feature is de-scoped.

Closed 2016-05-26.

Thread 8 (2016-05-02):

Implement "click" message LED animation

sfoster, 2016-05-02:
Write code to display a recognizable color/blink sequence when a "click" message is received from the paired device

punamdahiya, 2016-05-16:
Feature is code complete and tested on few devices, closing the issue

Closed 2016-05-16.

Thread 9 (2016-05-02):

Implement "double-click" message LED animation

sfoster, 2016-05-02:
Write code to display a recognizable color/blink sequence when a "double-click" message is received from the paired device

punamdahiya, 2016-05-16:
Feature is code complete and tested on few devices, closing the issue

Closed 2016-05-16.

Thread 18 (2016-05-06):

Creating BOM and wiring diagram for the prototype device

sfoster, 2016-05-06:
We need a  battery, charge/management module for it and a vibration motor on the device. So, while we're aim to maintain compatibility with the Particle "Internet Button", the device we hand to test participants will need a parts list / bill of materials and a wiring & assembly guide.

sfoster, 2016-05-06:
### Bill of Materials

Vendor links are just where I bought mine. In many cases equivalent parts can be substituted and purchased elsewhere.

* Particle Photon *without headers* [Particle store](https://store.particle.io/)
* USB LiIon/LiPoly charger - [Adafruit](https://www.adafruit.com/products/259)
* "Neopixel" WS2812 addressable LED strip. Non-waterproof, 60 LEDs per meter. (cut strip of 5 LEDs per unit) [Amazon](http://www.amazon.com/Mokungit-Programmable-Individually-Addressable-Non-waterproof/dp/B01D1EDDR8)
* 3.7v 2000mAh Lithium Ion Battery [Adafruit](https://www.adafruit.com/products/2011) - note that shipping restrictions apply. Max 8 per order, no USPS delivery.
* 12x12x7mm Momentary Tactile Push Button Switch 4 Pin DIP [Amazon](http://www.amazon.com/uxcell%C2%AE-12x12x7mm-Momentary-Button-Switch/dp/B009ERT2NQ)
* 10K Ohm 1/4 watt resistor [Adafruit](https://www.adafruit.com/products/2784)
* Pancake vibration motor [Adafruit](https://www.adafruit.com/products/1201)
* Mini USB Cable - A to Mini B [Amazon](http://www.amazon.com/StarTech-com-Mini-USB-Cable-USB2HABM6RA/dp/B004NO0L4O)
* Hookup wire for all the connections. E.g. [Adafruit](https://www.adafruit.com/products/1311)

sfoster, 2016-05-09:
Bill of Materials included in a the README file in commit 5f06df7

sfoster, 2016-06-06:
Wiring diagram is committed and referenced in the README.

Closed 2016-06-06.

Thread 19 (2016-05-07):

Reset mechanism

sfoster, 2016-05-07:
We need to make sure we have a simple way to reset the device, and wipe any stored wifi credentials. We may ask study participants to reset when handing back the devices just so there's no possibility those credentials could hang around and be used/abused after the study.

Possibly the 'reset' button on the Photon already does this. Lets confirm before resolving this issue.

kglazko, 2016-05-09:
I will investigate this.

kglazko, 2016-05-09:
Requires a Factory Reset- this can be done via the Mode button

Procedure:

The procedure is same as the one described above (DFU Mode), but in this case you should continue holding down the MODE button until you see the Core change from blinking yellow to blinking white. Then release the button. The Core should begin after the factory reset is complete.

   1. Hold down BOTH buttons
   2. Release only the RST button, while holding down the MODE button.
   3. Wait for the LED to start blinking yellow (continue to hold the MODE button)
   4. The LED will turn solid white (continue to hold the MODE button)
   5. Finally, the LED will turn blink white rapidly
   6. Release the MODE button

 https://docs.particle.io/guide/getting-started/modes/core/

punamdahiya, 2016-05-10:
I believe factory reset will wipe the code flashed on the device. If our goal is to wipe Wifi credentials stored on device, can we check if have a way to only delete stored WiFi without doing factory reset

punamdahiya, 2016-05-10:
Link here shows how to erase stored wifi network,  https://docs.particle.io/guide/getting-started/modes/core/#wi-fi-network-reset . We should test if this will suffice our need

punamdahiya, 2016-05-26:
Updated https://github.com/mozilla/smarthome.iot/tree/master/Prototype-UR2 with reset instructions. Marking issue closed.

Closed 2016-05-26.

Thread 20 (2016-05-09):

Add open source license to the repo

sfoster, 2016-05-09:
We want a license for the overall repo - which should be compatible with any open source licensed "libraries" and other software that we drew upon to devise "our" software that we are placing in GitHub. I.e. compatible with the LGPL license used by Particle for their firmware: https://github.com/spark/firmware/blob/develop/LICENSE

ezoehunt, 2016-05-10:
Quick google search turned up this for how to choose a license for:
[Open Source Hardware](http://www.open-electronics.org/how-to-choose-your-open-source-hardware-license/)

Assuming open source hardware license is new to Mozilla. Shall we ping Braden about this?

sfoster, 2016-05-10:
For now I've added an MIT license to the repo: 6d7c9e2 which as I understand it is compatible with the LGPL license Particle have attached to their firmware (though we are not re-distributing the firmware in our repo, we are building on top of it)

We'll need an appropriate license for the 3d files, also the overall design which we'll document (parts list, wiring diagram, final assembly). I have a recollection of classic software licenses like MIT being unsuited for these kind of assets?

ezoehunt, 2016-05-10:
Cool. For stuff like parts list, wiring, instructions - seems like a Creative Commons license would work.

For reference, found like link about [Open Content](https://en.wikipedia.org/wiki/Open_content).

punamdahiya, 2016-05-26:
Opened issue #25 to further refactor and bring out copyright code in separate file. Closing this issue for this study.

Closed 2016-05-26.

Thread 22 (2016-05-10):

Document end-to-end instructions

ezoehunt, 2016-05-10:
Adding this as a reminder of what we discussed Mon afternoon:

1. Parts List with links to all parts. Include all specifics so if an item is out of stock at the link, reader can find the part elsewhere.

1.  Wiring diagram and instructions for wiring the parts up

1. 3D .stl file that describes the basic enclosure we've designed

1. Instructions that describe how to put together the parts/wiring with the enclosure.

1. Instructions for getting the code onto the device. May come in 2 flavors: 1) for devs who would use Github, and 2) for novices who would use a simplified process.

Once we've got that, I'll try to build the end-to-end device using these instructions and improve the instructions as I go. Then we publish!

punamdahiya, 2016-05-26:
This is dependent on Issue #18

punamdahiya, 2016-06-09:
End to End instructions documented here:
https://drive.google.com/a/mozilla.com/file/d/0ByJ_mHuB-es3ckNXVHVpNDFPTUU/view

ReadMe file updated with instructions:
https://github.com/mozilla/project_haiku.iot/tree/master/Prototype

sfoster, 2016-07-07:
@mermi was able to build out a device on a breadboard following the instructions. There's more we can do next time but for now, we are all done here

Closed 2016-07-07.

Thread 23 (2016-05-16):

Log the time it takes to get a wifi connection and a ping

punamdahiya, 2016-05-16:
Log the time it takes to get the device connected to WiFi when it first comes online and respond to the click from paired device.

This is to investigate option to put the device to sleep (https://docs.particle.io/reference/firmware/photon/#sleep-sleep-) and improve battery life

kglazko, 2016-05-16:
`if (b.connecting()) {
	int startConnecting = Time.now();
}

if (b.ready()) {
	int successConnect = Time.now();
	int timeToConnect = successConnect - startConnecting;
	Particle.publish(CONNECTED_TO_WIFI, String(timeToConnect), 60, PRIVATE);
}`

kglazko, 2016-05-23:
Should we just put this in the set-up loop?

kglazko, 2016-05-23:
// We start with the setup function.
void setup() {
  Serial.begin(9600);
  b.begin();
  int startConnecting;
  if (WiFi.connecting()) {
    startConnecting = Time.now();
  }

if (WiFi.ready()) {
    int successConnect = Time.now();
    int timeToConnect = successConnect - startConnecting;
    Particle.publish(CONNECTED_TO_WIFI, String(timeToConnect), 60, PRIVATE);
  }
  b.attachClick(click);
  b.attachDoubleClick(doubleClick);
  b.attachLongPress(longPress);

  // Subscribe to paired device event event using Particle.subscribe
  // Subscribe will listen for the event SUBSCRIBE_EVENT_NAME and
  // when it finds it, will run the function handleEvent()
  Particle.subscribe(SUBSCRIBE_EVENT_NAME, handleEvent, MY_DEVICES);
};

sfoster, 2016-06-02:
If I understand correctly, this code isn't yet working properly. We want to capture the time it takes from reset and/or deep sleep to the time we are able to ping the particle service. If we can mark milestones along the way for acquiring a network connection etc. so much the better, but the key number here is how long will it be (could it be) to retrieve data. That includes startup time, time to acquire a network connection, get an IP address, resolve the particle.io name, issue a request and get a response.

punamdahiya, 2016-06-06:
To explore below option, first thing to find out when you power and log serial - Time needed

1. Power and WiFi connection - How long it takes
2. Power, start up and Particle Cloud - How long it takes
3. Difference between deep sleep and battery disconnected
4. Based on the above time needed , we can determine if we can use battery powered WiFi in our devices

Based on the above data we can determine the feasibility of below idea:
See if its possible to have device sleep up most of the time - ideally ping network every 5 seconds and make new connection and check with cloud service message queue if there is anything new

sfoster, 2016-06-06:
I started a spreadsheet with some initial results: https://docs.google.com/spreadsheets/d/19U1wRxKqDWiCAz9SEGUvcEZfHhzA5EnM32dGJ3jq4c8/edit?usp=sharing

sfoster, 2016-06-10:
So far its looking like we have a range from ~ 5s to 20s, which is a bit better than I had anticipated, but still slow enough that a power saving strategy to preserve the perception of real-time connectedness doesnt jump right out. It would be good to get more data to try to understand the range and distribution of these times we can expect. I'm assuming there will be outliers - networks are like that.

Then, I think the next step is to write some code to test out sleep/deep sleep and see how those numbers compare.

sfoster, 2016-07-05:
With the data logged in https://docs.google.com/spreadsheets/d/19U1wRxKqDWiCAz9SEGUvcEZfHhzA5EnM32dGJ3jq4c8/edit?usp=sharing, this issue can be closed. Basically we are seeing a range from around 3 seconds from powering up to getting the response from the "ping", to about 20 seconds. We should file a new issue for the follow up work outlined in the previous comment.

Closed 2016-07-05.

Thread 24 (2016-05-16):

Put Photon to deep sleep if WiFi module is turned off because of low battery

punamdahiya, 2016-05-16:
If photon has shutdown the wifi module (breathing white) https://docs.particle.io/guide/getting-started/modes/photon/#wi-fi-off,
there's no point in drawing more power from the battery and photon should deep sleep and wakes up when USB cable is plugged in to charge battery and RST button on photon is pressed.

punamdahiya, 2016-05-16:
One possible solution is to use function batterylevel() that checks analog value every 5 mins, if it falls below a threshold put the device to deep sleep mode

To wake up the device:
1.  Set a flag isConnected set to false at code startup
2.  If isConnected is false (that is device was never connected to Wifi), try to connect , If connected to Wifi, set IsConnected to true
3. If isConnected is true, check the batterylevel()

isConnected flag ensures that device goes into deep sleep from working mode once battery level raises alarm and will let device boot up normal once reset.(e.g. User plugs in charging wire and press RST button)

punamdahiya, 2016-05-26:
This feature is code complete and tested on few devices to sleep is A5 reading is < 3.0 which maps to 3.6V on multi-meter between VIN and GND.

Closed 2016-05-26.

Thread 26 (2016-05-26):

BLE Device - Make BLE device easier to switch on and off

punamdahiya, 2016-05-26:
For power management, we should look into powering on and off device with an external switch

punamdahiya, 2016-06-06:
Lets prototype this in work week using a single pull switch

punamdahiya, 2016-07-18:
Using the issue to figure how to power on and off BLE device using external switch

punamdahiya, 2016-09-16:
Code branched to https://github.com/mozilla/project_haiku.iot/tree/Haiku_BLE_Beta1, closing as won'tfix

Closed 2016-09-16.

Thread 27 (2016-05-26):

Log data from particle board

punamdahiya, 2016-05-26:
Create our own logging service to log data from device to an external file server / database

punamdahiya, 2016-06-06:
Need to figure out how to provision a server and an account for logging on cloud

punamdahiya, 2016-06-06:
Write a small node.js server that exposes REST API and  accepts post from specific URL and store data in database.

kglazko, 2016-06-07:
Discussed with Mahe and Sam and decided that GA/GBQ is a good solution for logging. I will be working on:

- Concreting out exactly what we want to log (what parameters/events/etc.)
- Deciding how we want to log (aka via direct POST in the code (bypassing particle publish), to GA directly or to Metrics API
- Getting some sample events to show up in Google BQ

mermi, 2016-06-29:
for the node.js server I have question the data base should be in a specific tool like mangodb ?!

sfoster, 2016-06-30:
@kglazko can you work with @mermi on what needs to happen here? As I understand it we can send data directly to the GA server. I'd like to see some prototype code using that API from the Particle button (i.e. in C++ running on device) so we can work out if it make sense to code to our own API and relay logging calls off to GA (or whatever backend), or make the connections directly from the device and avoid this middle-man node.js server altogether.

kglazko, 2016-06-30:
Here is an example of usage https://github.com/tamarahills/metrics_controller/blob/master/examples/node_demo.js

mermi, 2016-07-01:
yeah @sfoster I worked on that API with russ and Tamara, it is a rust library and now the library works with Java, c++ and JS client. So you wanna make the same thing ??

sfoster, 2016-07-01:
I want to get some working C++ demo code in our repo that demonstrates logging data from a Photon device using this API.

sfoster, 2016-07-07:
@mermi can you update this issue with the current plan. Perhaps we need to close this one and open a new ticket as it is mostly concerned with creating a logging service - which I believe it turns out we will not need.

mermi, 2016-07-15:
So today the c++ code works sending data from Particle to GA and here the code https://github.com/mermi/Logging-service/blob/master/logging.ino We are willing to get it works from Webhooks to GA now something happening that doesn't work from Webhook today will keep figure out the issue.

mermi, 2016-07-18:
concerning Webhook, I tried to use https://thingspeak.com for sending Data with Webhook to ThingSpeak and it works https://thingspeak.com/channels/135707 I just followed the documentation in Particle Docs We need to figure out why it doesn't work from Webhook to GA that time will look on it more with Kate when she is up to

Closed 2016-08-29.

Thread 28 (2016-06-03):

Get a test enclosure print from Shapeways

sfoster, 2016-06-03:
We should verify the current model prints OK with a 3rd party service like Shapeways, and debug any issues before calling it done

sfoster, 2016-06-06:
I've ordered a print of the enclosure.stl in the "White Strong & Flexible Polished" material. It will get shipped in 1 week - i.e. 5 working days after the order, and arrive (depending on how you ship) 8 or so days after placing the order.

sfoster, 2016-07-07:
(1) White Strong & Flexible Polished cost $30.39 shipped from Shapeways, arriving about 1-ish week (5 business days) from when I ordered. Quality was good and the hinge and latch worked as-is with no clean-up necessary. For this material, I would feel pretty good about developing the prototype on a home/hobbyist printer with ABS and getting final prints from Shapeways (assuming cost wasn't a factor.) and knowing what to expect. The time to print and ship from this or any similar vendor makes it a case-by-case decision.

Closed 2016-07-07.

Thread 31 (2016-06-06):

Recycle existing hardware

corv89, 2016-06-06:
I've got an idea for a "smart home/IoT" type project I would like to implement.

Is it possible to re-purpose Firefox OS developer phones or a Raspberry Pi for Haiku?

sfoster, 2016-06-06:
We could prototype something with the old Flame phones, but there aren't enough out there for this to be a viable approach - we would need to figure out compatibility with at least a few more older android-capable phones. As we've seen with FxOS, that's quite a lot of work up-front, and ongoing.

This project is steering towards a minimal-interaction, "ambient" communication device for teens, rather than anything "smart home" - which is why we changed the project name, so I'm not sure this is the best group to consider your idea. But if you want to join the #smarthome IRC channel we can discuss?

corv89, 2016-06-06:
Thanks for the heads-up, I'll stick to HTML5 then.

Ambient communication sounds like a novel idea. I'll be keeping an eye on FirefoxOS's new directions.

Best of luck to your project!

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

Closed 2016-07-07.

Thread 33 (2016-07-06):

Extend battery life for WiFi devices

punamdahiya, 2016-07-06:
Follow up of https://github.com/mozilla/project_haiku.iot/issues/23. This issue explores options both in code and UX, how battery life can be extended for devices using WiFi.

- See if its possible to have device sleep up most of the time - ideally ping network every 5 seconds and make new connection and check with cloud service message queue if there is anything new

- Write some code to test out time taken to connect to WiFi after sleep/deep sleep and see how those numbers compare

sfoster, 2016-07-07:
I think we are still interested in doing a little experimentation here - we've talked about sleeping the Photon's microcontroller (and radio) but I would like to see working code that accomplishes this, waking up say every 5 minutes to make a request, wait for response and go back to sleep. We should then be able to get actual power usage numbers and estimate battery life.

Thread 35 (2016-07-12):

Status service

sfoster, 2016-07-12:
Prototype a simple web service with end-point(s) for watching status (available/online/busy etc) flags.

sfoster, 2016-07-12:
Commit ccb267ac8b046b3e08689f967541660de35fa64a has a simple node.js (express) server with a /status endpoint in text/plain, json and html flavours. The value is backed by a file of the same name which holds the value, and whose last-modified date is given in the response. This is proof-of-concept code and dangerously lacking in any of the reasonable safeguards normally applied to limit who can update the value, enforce a limit on the size of the value etc.

sfoster, 2016-07-21:
The current code meets the initial requirement. We'll have follow-up issues already filed for access control etc.

Closed 2016-07-21.

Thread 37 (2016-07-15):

Test Client - HTML test client for status service

sfoster, 2016-07-15:
Lets have a test page that we can use as a prototype client for working out the interactions with the status server(s), and the lights, interactions etc.

I outlined something in this gist...
https://gist.github.com/sfoster/da29b7f9242d955ca116586f6a5599f3

..but feel free to implement it however makes sense. Bear in mind this is throwaway code. It should be able to poll the server and light up the "LEDs" when it gets some status value it recognizes. Then we can work out the message format and other details here really quickly before porting to the device hardware and embedded code.

mermi, 2016-07-15:
Great, thank you Sam for the comments in the example and for the Canvas you would them display Rainbow lights ?!!

sfoster, 2016-07-15:
I'll get this started by adding a skeleton file to the status-server so we can load it directly from that server when it is running.

@mermi sure. Lets treat each canvas as a Neopixel/LED so we can preview some different effects. You can then port over the rainbow function from the Arduino code

sfoster, 2016-07-29:
We have other issues covering next steps; this is complete as of 813e587c00bf87de6aaaa688b64703769e2bc7ee

Closed 2016-07-29.

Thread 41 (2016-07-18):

Bluetooth LE connection to Smart Phone

punamdahiya, 2016-07-18:
Use BLE Nano development board with Nordic nRF51822 BLE peripheral and central module to send and receive data from SmartPhone app.

punamdahiya, 2016-07-18:
Implement bidirectional communication  between the BLE central (smartphone) and BLE Nano using Arduino BLEPeripheral library https://github.com/sandeepmistry/arduino-BLEPeripheral

punamdahiya, 2016-07-26:
Use ble.scan(services, seconds, success, failure);
https://github.com/don/cordova-plugin-ble-central#scan

to scan for BLE peripherals. Pass service_uuid: FFF0 of the BLEBuzzService to ble.scan function. This scans only those BLE peripheral devices that are advertising the BLEBuzzService.

punamdahiya, 2016-07-29:
Updated the service and characteristics UUID - 128 bit to work with Android cordova app checked in github below
https://github.com/mozilla/project_haiku.iot/tree/master/Bluetooth/nRF51822/PhoneGap/BLE-Buzzy-Pixel

punamdahiya, 2016-07-29:
Android app above tested with BLE device to send and receive two way communication. Opened Issue #62 for slow canning

Closed 2016-07-29.

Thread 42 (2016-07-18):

Display LED status color using NeoPixel when status changes

punamdahiya, 2016-07-18:
Use neopixel to receive and display status data sent from SmartPhone app.

punamdahiya, 2016-07-18:
Sketch here https://github.com/mozilla/project_haiku.iot/tree/master/Bluetooth/nRF51822/Arduino/BLE-Peripheral-NeoPixel shows basic LED animation when the status is changed from Smart Phone using BLE peripheral scanning iOS app Lightblue or the Android App - B-BLE

punamdahiya, 2016-07-22:
Implement  BLEBuzzService with a showStatusCharacteristic (Read-Write BLECharacteristic) that receives status from a central device for 'n' neopixel in an array. The status received is than parsed and flash respective Neopixel with Red (offline) and Green (online). Again these requirements are WIP and not finalised.

BLECentral device such as SmartPhone will send data at specified interval and will be handled inside an eventHandler showStatusCharacteristicWritten on BLE Peripheral device where for any change in status,  respective NeoPixel will be updated.

For simplicity , the data format sent to showStatusCharacteristic can be of format 0x00 for offline and 0x11 for online, for five offline neopixels, the data passed will be in hex format 0x00 00 00 00 00, any non zero value indicates online status

punamdahiya, 2016-07-26:
Use ble.write(device_id, service_uuid, characteristic_uuid, data, success, failure);
https://github.com/don/cordova-plugin-ble-central#write
for
device name BLE-Buzzy-Pixel
service_uuid: FFF0
 characteristic_uuid: FFF1
data in the format 0x11 00 11 00 11

punamdahiya, 2016-07-29:
Updated the service and characteristics UUID - 128 bit to work with Android cordova app checked in github below
https://github.com/mozilla/project_haiku.iot/tree/master/Bluetooth/nRF51822/PhoneGap/BLE-Buzzy-Pixel

The Android app UI sends five BFF status in decimal -17  for available and 0 for offline

punamdahiya, 2016-07-29:
Closing the issue after testing with Android app . Issue #61 filed to follow up with reading BFF status by SmartPhone app from cloud services

Closed 2016-07-29.

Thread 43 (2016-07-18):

Click to view/acknowledge or set status from BLE devices

punamdahiya, 2016-07-18:
One option is to “acknowledge” the message on the BLE device by clicking a button on there - similar to seen/unseen notifications, read/unread messages

User can click a push button and input the status that will be notified to SmartPhone app using Read Notify service

punamdahiya, 2016-07-18:
Sketch here https://github.com/mozilla/project_haiku.iot/tree/master/Bluetooth/nRF51822/Arduino/BLE-Peripheral-NeoPixel on BLE device notify SmartPhone with status data '0' or '1'  when a push button  is pressed. The status can be viewed from Smart Phone using BLE peripheral scanning iOS app Lightblue or the Android App - B-BLE

punamdahiya, 2016-07-25:
processButonChange inside https://github.com/mozilla/project_haiku.iot/commit/d5fc3ac1825c5626dce80d2e0e7f3aa2df0871b8 need to be updated to handle click , As of now press of button is read as 1 and release is 0

punamdahiya, 2016-07-26:
Set status by pressing first or home LED from the BLE device https://github.com/mozilla/project_haiku.iot/commit/9bd49cb2c16cdfe38341d2cc39e56401f6958138

punamdahiya, 2016-07-26:
Reopening to mark code complete and close the issue once tested with Adnroid app

punamdahiya, 2016-07-26:
Use https://github.com/don/cordova-plugin-ble-central#startnotification or
https://github.com/don/cordova-plugin-ble-central#read to read the status of the characteristic on device name BLE-BUZZY-PIXEL
Service_UUID: FFF0
Characteristic_UUID: FFF2

punamdahiya, 2016-07-29:
Updated the service and characteristics UUID - 128 bit to work with Android cordova app checked in github
https://github.com/mozilla/project_haiku.iot/tree/master/Bluetooth/nRF51822/PhoneGap/BLE-Buzzy-Pixel

The value Home BLE Device status displayed in Android App UI is in decimal - 17 for available and 0 for offline

punamdahiya, 2016-07-29:
Closing the issue after testing with Android app, Filed issue #61 to update status on cloud

Closed 2016-07-29.

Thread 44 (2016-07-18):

BLE Device - Battery Power BLE Nano module

punamdahiya, 2016-07-18:
[sfoster] There are “fuel gauge” modules for monitoring status of LiPo batteries we could use. Or the voltage divider we used before is also reasonable if there are ADCs on the Nano module (analog inputs)

punamdahiya, 2016-07-20:
Tried and was able to successfully power BLE Nano (without USB MK20 module)  with Adafruit LIPO charging module used in UR#2 and 110 mAH LIPO battery

punamdahiya, 2016-07-29:
WIP requirement:
On Low power: Probably want a buzz/light combination for when battery needs to be replaced. Maybe also a notification in the Bluetooth app.

punamdahiya, 2016-09-16:
Code branched to https://github.com/mozilla/project_haiku.iot/tree/Haiku_BLE_Beta1, closing as won'tfix

Closed 2016-09-16.

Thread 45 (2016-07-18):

Estimate power usage of an always-on simple cellular device

sfoster, 2016-07-18:
We need to understand the parameters involved if we use cellular as our wireless technology. What power usage can we expect if the device is able to send/received 24hrs a day? What are the variables and what are the implications of optimization? I.e. to use a smaller battery or charge less frequently, what options would we have?

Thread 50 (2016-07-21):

Test Client - "LED" animations in example client

sfoster, 2016-07-21:
We want to be able to preview and experiment with different interactions, effects and animations in this HTML/JS client. We should be able to animate through a sequence of colors (rainbow) over some period of time, or back and forth between colors, pulse a single color and so on. For this issue, lets focus on animating each LED/element individually. Eventually we should also be able to animate the strip as a whole.

Note, the current client code uses Canvas elements. If it turns out to be quicker to implement variations using DIVs and CSS animations we can change this

sfoster, 2016-07-26:
I think describing the animations as keyframes (data) to the extent possible is probably the right approach here. We can have some light-weight functions that unpack the animation data and do the tweening and easing on device. CSS animations provide most of what we need - though we'll need a solution for animations that span elements. I'm not suggesting we interpret CSS at runtime in the microcontroller, just keep a similar paradigm and define equivalent data types for playing these animations on device.

sfoster, 2016-08-05:
First round is landed in https://github.com/mozilla/project_haiku.iot/commit/39c4d9f3527412aed9b22927391d35da2f85c0ea

sfoster, 2016-08-13:
The final part of this is up for review at #121
It integrates the SlotsAnimationManager with the client, so that the current status should be reflected, and the polling should stop when the mySlot.status is '0'.
This makes the sideBySide.html pretty cool - as each user has different slots assigned so setting one to inactive has this trickle effect as that LED goes dark in the others

sfoster, 2016-08-16:
Fixed in ccfa553e9447020b9f41a9e323018976a3b2cdd3 and cd83400b95d62a2290d35c4835539b6a637f2ee8

Closed 2016-08-16.

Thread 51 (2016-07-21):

Test Client - Make "LED"s clickable in the example client

sfoster, 2016-07-21:
One idea we are considering is to make each "pixel" also a clickable button. Perhaps clicking a particular button sends the ad-hoc "rainbow" message to that person - like a poke. We'll want to try different interactions using click/double-click/long-click, so this issue involves adding the ability to register handlers for each click variation, and perhaps triggering an animation to indicate success

sfoster, 2016-08-02:
The ad-hoc "rainbow" mesages will need to come later. For now lets just set up a click handler so we can extend it when we have the ad-hoc messages support on the server.

sfoster, 2016-08-03:
This was hooked up in 115fc40aea7e71c3f3d8c79e34706dc64cb9f75f, we only react to clicks from 'self' currently and can extend this later to send messages or whatever.

Closed 2016-08-03.

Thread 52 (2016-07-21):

Test Client - side by side client page

sfoster, 2016-07-21:
Create a new page with iframes to show multiple example client pages side by side, so we can experiment with the interactions. We'll need to add a way for each client to know who it is (what its status feed URL is) and which status feeds it is subscribed to.

The goal is to be able to click/tap on a button in one iframe and see the result in the other iframe

mermi, 2016-07-25:
I am pretty sure that you mean https://github.com/mozilla/project_haiku.iot/pull/56 and I think it needs more things to add

sfoster, 2016-07-29:
Looks like a dupe of #56

sfoster, 2016-07-30:
Oops sorry for the confusion, this is very much open.

sfoster, 2016-08-03:
Fixed in 115fc40

Closed 2016-08-03.

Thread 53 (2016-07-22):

Bill Of Material - BLE Buzzy Pixel

punamdahiya, 2016-07-22:
1. BLE Nano & MK20 USB Board - http://redbearlab.com/blenano/
2. [Optional] RedBearLab nRF51822 Pinout - http://redbearlab.com/redbearlab-nrf51822/ (Ideally BLE Nano should suffice, for beginners nRF51822 dev board is recommended instead of BLENano at first as it has easy pin out interface)
3. "Neopixel" WS2812 addressable LED strip. Non-waterproof, 60 LEDs per meter. (cut strip of 5 LEDs per unit) [Amazon](https://www.amazon.com/Mokungit-Programmable-Individually-Addressable-Non-waterproof/dp/B01D1EDDR8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)
4. Sparkfun inventor kits part for resistor, buttons, led and jumper wires - [Sparkfun](https://www.sparkfun.com/products/13110)
5. Breadboard - [Sparkfun](https://www.sparkfun.com/products/12002)

sfoster, 2016-07-22:
Can you also drop this in a README alongside the code that goes with it?

punamdahiya, 2016-07-22:
Done. https://github.com/mozilla/project_haiku.iot/tree/master/Bluetooth/nRF51822/Arduino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

Closed 2016-07-22.

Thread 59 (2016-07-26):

BLE Device - Meta Issue - Send ad-hoc message by pressing BFF LED

punamdahiya, 2016-07-26:
Press of BFF's  LED should send message and display rainbow animation on respective friend BLE device

punamdahiya, 2016-07-29:
WIP requirement:
I can send an ad-hoc message to anyone in the group.
I can send 1 ad-hoc message at a time (no “send to all at once”).
I can send an ad-hoc message when my status is “on” and the status of the person to whom I’m sending it is “on.”
If my status is “off,” the physical device blocks me from doing anything with it (the device is “dark”) except for toggling my status to “on.”
If my friend’s status is “off” when I try to send an ad-hoc message, I see an “error state.”
When I send an ad-hoc message, I receive a “message sent” confirmation.
When I receive an ad-hoc message, I know it’s from X because X’s status indicator blinks twice (or some other “this is who sent this” indicator).

punamdahiya, 2016-09-16:
Code branched to https://github.com/mozilla/project_haiku.iot/tree/Haiku_BLE_Beta1, closing as won'tfix

Closed 2016-09-16.

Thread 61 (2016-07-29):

SmartPhone App - Read and write status on cloud service through a simple on/off toggle

punamdahiya, 2016-07-29:
This is follow up of issue #43 , which sets the status inside the Android app through a simple on/off toggle. The scope of the issue is to communicate this status to cloud service via smartphone app and test end to end communication between two BLE devices

punamdahiya, 2016-07-29:
WIP requirements:
- Can change my status through a simple on/off toggle.
- there are only 2 statuses: On or Off.
- When my status is “on,”
I see visual confirmation of that.
I can see the current status of anyone in the group.
I can send and receive ad-hoc messages.
- When my status is “off,” the device is “dark”
I see visual confirmation of that.
I cannot see the status of anyone else in the group.
I cannot send or receive ad-hoc messages.

punamdahiya, 2016-08-17:
Tested end to end basic status communication without handling slots between two BLE devices. Opened follow up issues #138, #93, #130, #137, #128, #129 noticed while testing the flow.

Closed 2016-08-17.

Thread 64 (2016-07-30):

Status Service - Reorganize routes to use a /user/{id}/{noun} pattern

sfoster, 2016-07-30:
We arrived at status{id} organically. If we are contemplating multiple users per server instance, /user/{id} is a better URL pattern to build on. Then we can have /user/0/status, /user/0/message, etc.

We'll need to update the routes themselves in src/index.js, as well as any client code that makes requests.

sfoster, 2016-08-05:
Fixed in 5340d599b4a795cc18d745b20e8413fff6a71c9a - but see follow up landing 4df9199fa43f59624b0d2de865f95472ffc3c1b4 that fixes 405 Method not allowed errors and a couple client.js stragglers.

Closed 2016-08-05.

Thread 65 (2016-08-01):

SmartPhone App - Cordova app to handle communication even when app is closed or invisible

punamdahiya, 2016-08-01:
Scope of this issue is to investigate and implement Android app as background service that is it can
execute the code in the app even when app is closed.

punamdahiya, 2016-08-01:
Android has Services that could be used to keep connections alive while moving between activities, investigate if its possible to implement that using PhoneGap.

punamdahiya, 2016-08-01:
Related links:
http://stackoverflow.com/questions/10343828/creating-an-android-service-with-phonegap-have-phonegap-app-run-even-when-clos
http://www.codeproject.com/Questions/633535/Make-Phonegap-app-run-in-background

kglazko, 2016-08-11:
https://github.com/mozilla/project_haiku.iot/tree/backgroundtest Branch with perpetual background running on Android.

punamdahiya, 2016-08-16:
@kglazko quick question how do we test that the plugin let app live in background always? By default without plugin, I navigated to another app, forcing buzzy-pixel in bkg and see the app passing http requests.
Looks like thats Android default behavior, I am not sure if there is time cap to it and the background app is force killed after certain time.

punamdahiya, 2016-08-23:
Looks like there's a time cap, I have noticed after ~20 minutes of screen turned off, status doesn't update on connected BLE device.If screen is turend on after 20 minutes  request goes through and status updates. WIll integrate recommended plugin to test this use case.

punamdahiya, 2016-09-16:
Code branched to https://github.com/mozilla/project_haiku.iot/tree/Haiku_BLE_Beta1, closing as won'tfix

Closed 2016-09-16.

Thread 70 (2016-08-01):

Status Service: Add route for accepting messages

sfoster, 2016-08-01:
We need a way for a client to send messages to another client. This end-point should only accept POSTs and expect a sender userid in the post body(?)

sfoster, 2016-08-01:
Enabling access control on this - so only expected users can send message to me - pre-supposes the server has a notion of who the designated users are. Currently we imply this through the presence of a file in /data/. For this reason, we should move any controls around who can post to #36 and follow-ups on that issue, and assume the sender id is valid.

I see our first pass at this working like so:
UserA has a device with includes a LED/button that represents UserB, and vice-versa. When UserA clicks the UserB button, a message is POSTed to /users/userB/message with some numerical value (e.g message=1.) We'll create/update a message file for UserB with the value and last-modified timestamp just like the status file format. The server should return a ok/200 response if userB exists.

UserB's client subscribes (via polling for now) to its own /users/userB/message channel and sees the update there. For this issue its enough to console.log() recognition of the message.

sfoster, 2016-08-06:
expect a PUT request like:
{
  sender: 'http://localhost/user/someid',
  value: 1
}
add a last-modified property to the object and write that to the data/user/userid/message file.

So that, GET /user/userid/message returns:
{
  "sender": 'http://localhost/user/someid',
  "value": 1,
  "last-modified": "2016-08-06T00:11:31.254Z"
}

I'm also aware that we have much potential for confusion with sending numeric data as strings. Lets keep it consistent for now and file a new bug to fix it across the board.

Closed 2016-08-09.

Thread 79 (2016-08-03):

Test Client - Highlight self in the row of LEDs/slots

sfoster, 2016-08-03:
We need a way to visually distinguish which of the slots/"LEDs" represents myself. Maybe make it a bit bigger? Or position it up/down from the rest or add a different border?

sfoster, 2016-08-03:
@mermi can you review the small patch for this in #82

sfoster, 2016-08-03:
Fixed in 2239ade67c4a2494349236eb1ada9a9b1192cc5f

Closed 2016-08-03.

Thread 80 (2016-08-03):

Test Client - Switch to using divs not canvas for LED/slots

sfoster, 2016-08-03:
Turns out we just need to animate color on each slot/LED, and any overlays or labels will be actually easier to accomplish with HTML/CSS.

mermi, 2016-08-03:
I already start that the CSS part, but I am going to make some change in the client.js because there in the init and render we are using canvas to change the color of each Led

sfoster, 2016-08-04:
@mermi in animations.html there's a setPixelNodeColor function that we could add to client.js. It supports both RGB and HSV colors which could be handy.

mermi, 2016-08-04:
So we would use it for instead of the Standard Rainbow one right @sfoster ??

sfoster, 2016-08-04:
Fixed and landed in 5946a9f5c4f1631763f515f4d6c3733a56d97f30, thanks!

Closed 2016-08-04.

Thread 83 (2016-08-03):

Test Client - Mock up an announcement 'buzz'

sfoster, 2016-08-03:
We want a vibration to announce incoming status changes. Lets find a way to mock that up in the HTML client. We can play a CSS animation, a sound, show a 'buzz' element or whatever gets the message across.

sfoster, 2016-08-09:
My suggestion would be an <audio> element added to example.html, with some royalty-free buzz sound clip from somewhere like http://www.flashkit.com/. We just need a function we can call to play the sound for some given amount of milliseconds: function buzz(ms) { ... }

sfoster, 2016-08-13:
Landed in a78190b680d0fceb5cb0d41844ed9ad9e3ef7585

Closed 2016-08-13.

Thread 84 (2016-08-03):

Test Client - Create all 7 clients in the side-by-side view

sfoster, 2016-08-03:
We decided the band should have slots for 6 friends, and one for yourself. So, 7 in total.
The server doesnt currently know about a user5, so we may need to create that data file and commit it.
We'll also probably need to adjust the styling (size/positioning) in example.html / client.css to get them all to fit in a reasonable window size.

sfoster, 2016-08-05:
Fixed in 65f8413c6e2c590681779323048a8813b04a4c0d
Note this doesnt include any resizing/scaling of the iframes or their contents. Lets open a new issue for that if it is deemed necessary.

Closed 2016-08-05.

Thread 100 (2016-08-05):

Status update failures (405 Method not allowed)

sfoster, 2016-08-05:

sfoster, 2016-08-05:
We tracked this down to the serve-index middleware. That and a couple other stragglers to get the client-side code in agreement with the API landed in c022a2299c33294b8755be9016993f0cdc4b0e86

Closed 2016-08-05.

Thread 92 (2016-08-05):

SmartPhone App - Setup/configure your BLE device

punamdahiya, 2016-08-05:
When the app first opens ,
a) UI shows nearby BLE peripheral
b) Click on the BLE device to connect
c) Once connected, app should allow user to search the friends (and their device) and setup the slots (assign the decal) on the device

Edge cases questions:
a) How to handle if there are two or more BLE devices (bracelets) scanned by an app?
To keep it simple , should all the other BLE devices switched off while setting up and configuring a specific BLE device

punamdahiya, 2016-09-16:
Code branched to https://github.com/mozilla/project_haiku.iot/tree/Haiku_BLE_Beta1, closing as won'tfix

Closed 2016-09-16.

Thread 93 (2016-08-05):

SmartPhone App - Update cordova-ble-central plugin to cordova-plugin-bluetoothle to handle UI to connect/disconnect BLE device

punamdahiya, 2016-08-05:
Once a BLE device is configured and connected to a smart phone , it should remember the device and settings. It should stay connected unless explicitly disconnected via a disconnect button on the app.

Once a device is successfully setup and connected, subsequent load of the SmartPhone app should display the connected BLE device page with List view of friends and status.

If disconnected, BLE device should free up to be scanned and connected by another smartphone app.

atilag, 2016-08-08:
Android Bluetooth API offers some functionality to handle automatic reconnection, and "bonding" devices (so you don't need to pair them manually every time, just once).
So a typical workflow to address the reconnection issue could be:
1. Start LE Scanning
2. When your device shows up in the list, you should connect to it [using](https://developer.android.com/reference/android/bluetooth/BluetoothDevice.html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):
`device.connectGatt( context, true /* autoconnect */, connectCallback );`
This will handle reconnection for you, so when the device you are connected to goes out of the scope, you will receive an "onConnectionStateChange" event into the connectCallback, warning you about the device going offline, but when it comes online again, this very same callback will warn you again about it too, so you can basically monitor the state of the connection, but don't need to call .connect() every time.

For the bonding part, there's a device.createBond() method call that will bond both devices, so the next time you perform a LE scanning, you will get the device instantly in the device list, and connect to it without pairing of any kind. Anyway, I haven't tried that with BLE devices before... so let me try a simple PoC program to see how actually behaves (the Android doc is very vague sometimes).

atilag, 2016-08-08:
As long as you are using PhoneGap, you may find this plugin better suited for your app https://github.com/randdusing/cordova-plugin-bluetoothle. It seems to have reconnecting and bonding features, so maybe supports encrypted communications as well.

punamdahiya, 2016-08-23:
Updated plugin, opened issue https://github.com/mozilla/project_haiku.iot/issues/154 for handling disconnect and reconnect to last connected device

Closed 2016-08-23.

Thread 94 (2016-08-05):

SmartPhone App - status, message, battery level client

punamdahiya, 2016-08-05:
1. SmartPhone app should allow user to set status from the SmartPhone app
2. Smart phone app should let user send message to a friend
3. Smart Phone app should display battery level

punamdahiya, 2016-09-16:
Code branched to https://github.com/mozilla/project_haiku.iot/tree/Haiku_BLE_Beta1, closing as won'tfix

Closed 2016-09-16.

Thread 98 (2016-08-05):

Status Service - Create a user/{userid}/slots API

sfoster, 2016-08-05:
We need a way to store which slots are assigned to which users. Each user's device has 7 slots, where slot 0 is always the "self" slot.  I propose a 'slots' data file under the user's data directory with a simple URL per line. Or a json data file with an array might be clearer? I guess the array could potentially be sparse - at any given time, a user might have no friend assigned to one slot.

The value should be a URL. Eventually I would like this to be a fully qualified url, allowing for users to exist elsewhere on the web, not just on this particular server/host. But for now, a relative url e.g. /users/2 would work. We'll assume our URL convention is known on the client, so the client can assemble URLs to request status and send messages to a given user.

sfoster, 2016-08-09:
Read API for slots landed in 45ed694d75483019266f9eb9672b500f0cd5a83f, we can open a new issue when we need slots management

Closed 2016-08-09.

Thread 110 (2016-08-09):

Test Client - use slots API to configure which status URLs are monitored

sfoster, 2016-08-09:
In client.js, we've hard-coded the 'statusItems' list. We'll need to refactor and extend existing functionality to first fetch the slots for the current user* and then start polling for status changes

* You can know what the current user is by checking config.id. See similar checks elsewhere. The notion of a user is very ad-hoc and implied currently. If accomplishing this would be simpler by first defining a simple User prototype, please file and work on that issue first. But assume this is throw-away code and do the simplest thing first.

sfoster, 2016-08-13:
Fixed in 33b25986bbb92215cccd9ca352a15ac054e16368

Closed 2016-08-13.

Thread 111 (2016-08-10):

Package up hardware kit for Jim

sfoster, 2016-08-10:
Jim Porter (irc handle squib) will be helping us out for a bit starting next week. We need to breadboard the hardware (BLENano kit, neopixels and buttons) and send it over to him so he can set up his environment and start coding next week

sfoster, 2016-08-11:
I sent a goody box with some components and other stuff that may prove useful 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

The tracking # is https://wwwapps.ups.com/WebTracking/track?track=yes&trackNums=1Z71EY050295653985&loc=en_us

The breadboard with the BLE Nano kit is boxed and I'll get over to FexEx today to send it off.

sfoster, 2016-08-12:
BLE Nano & breadboard should arrive via FedEx on Saturday a.m.
Tracking number: 783806500639

Closed 2016-08-12.

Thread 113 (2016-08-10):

Vendor meetings

Mahendranadh, 2016-08-10:
Meet with vendors, document services/offering to identify a suitable team to help us get going on 2nd prototype.

sfoster, 2016-08-13:
Will open a new issue for any follow-up meetings next week

Closed 2016-08-13.

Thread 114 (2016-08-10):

UI Mock up for Mobile status

KatieCaldwell, 2016-08-10:

KatieCaldwell, 2016-08-12:
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

KatieCaldwell, 2016-08-12:
@sfoster @punamdahiya @ezoehunt here's a first pass at a simple wireframe (2 states) for status ONLY ui app. Feedback and thoughts requested.

KatieCaldwell, 2016-08-12:
question: when my status is unavailable, is this the same as OFF for this experiment? If yes, then like idea 1, when my status is OFF, my friends' status isn't available to me (all OFF).

sfoster, 2016-08-12:
Yes, my understanding for this initial experiment is that setting my own status to off/unavailable is effectively the same as going offline and turning off the device: all status changes and other updates are disabled. Maybe that isn't exactly what we want eventually, but this seems like a simple, testable assertion. If people dislike this, we'll hear why and I think that puts us in a better position than adding features at random

KatieCaldwell, 2016-08-12:
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

KatieCaldwell, 2016-08-12:
@sfoster v2. OFFline status

ezoehunt, 2016-08-15:
@KatieCaldwell  First ui mockups - yay!

In the toggle, do you press the black square to switch status?

I made a version to remove some words. What say you?

By "log out," do we mean log out of the entire application? For this version, we may need that. But I don't think we'd have "log out" on the physical wearable. Seems a part of the Bluetooth app..

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

sfoster, 2016-08-15:
This looks good to me. I'd like to file some issues to get this implemented. We'll make a start assuming its going to be something along these lines.

KatieCaldwell, 2016-08-16:
@ezoehunt
Log out - was only because I was assuming (I know!) we'd need to log in somehow to get access the webpage and change your status.

And yes, the only interaction is toggling ON/OFF your own status. For this first pass, it's my understanding that this is the only requirement.

Open Questions (for v2)
• How might we add/remove 'friends'

punamdahiya, 2016-09-16:
Code branched to https://github.com/mozilla/project_haiku.iot/tree/Haiku_BLE_Beta1, closing as won'tfix

Closed 2016-09-16.

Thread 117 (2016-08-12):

Test Client - Mobile browser compatibility

sfoster, 2016-08-12:
We are going to want to build off the test/html client for our dogfooding/study mobile-web client. Lets start by ensuring we've got reasonable cross-browser compatibilty in the current major (mobile) browsers. We don't need exhaustive backwards compatibility, it should just work in the 1 or 2 popular/significant browsers for both iOS and android. I.e. Firefox for android, Safari (and Fx for iOS? not an iOS user, you tell me), Chrome.

Off the top of my head:
* Check and find alternatives to gecko-isms like Array.forEach. Do let and arrow functions work everywhere? May need to refactor if not.
* CSS: I don't think we have any -moz- prefixes, but some unprefixed properties may need -webkit prefixed variations?
* Audio: our buzz sound clip is an OGG file - we'll need an MP3 as well.

Please update this ticket with findings before starting any major changes so we can discuss.

mermi, 2016-08-16:
For the Audio there is a bunch of online converter we could convert the OGG file we have to MP3(this is already done)
For CSS we will need to add the media queries for Specific Browser on iOS or Android with -webkit-min-device-pixel-ratio we will need to add -webkit for border radius and scale (I am already working on that in another css file named mobile.css)
Searching for alternatives to Array.forEach didn't make any change on that yet
now I have a quick question if I want to run the new html page on my phone how to do it ?!

mermi, 2016-08-16:
It seems liek the Array.forEach works well in needed browser but it takes some ms for that looking here: https://benhollis.net/blog/2009/12/13/investigating-javascript-array-iteration-performance/

sfoster, 2016-08-16:
AFAIK, the static methods on Array (vs the methods on the Array.prototype) were never implemented outside of Firefox/Gecko. Unless we observe a performance problem, I don't want to worry about micro-optimizations like these. And IIRC the results vary across browsers anyhow.

sfoster, 2016-08-16:
I just grepped *.js for Array.* and I don't see any instances of that pattern any more, so that's good.
We do have some arrow functions though and a couple uses of `let`.

sfoster, 2016-08-18:
@mermi I took your PR and worked on it some: https://github.com/mozilla/project_haiku_status_api.iot/pull/6

sfoster, 2016-08-23:
The last of this landed in https://github.com/mozilla/project_haiku_status_api.iot/commit/e2c19db3fa18d78dc03abde73ea944ad0a021414

Closed 2016-08-23.

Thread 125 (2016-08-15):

Make plan to deploy to Heroku account

sfoster, 2016-08-15:
We need a Heroku account to deploy our Status server to.
Answer questions like:
* How will we do billing,
* Access/usage logs?
* How to enable admins?
* Is the filesystem-based data files still practical on Heroku?
* How to deploy updates - from github directly?

sfoster, 2016-08-17:
Depends on #134

sfoster, 2016-08-17:
* Billing: in the short term we'll use my Heroku account and I'll expense the charges.
* Logs: Heroku provides logs using their shell tool: heroku logs --tail, not sure if there's some out-of-the-box access logs available, or if we need to roll that in?
* We (I) can add collaborators, they should see a 'haiku-status-api' app when they log into their Heroku dashboard?
* Touching the data files currently involves pushing changes to the master branch, and updating the `heroku` remote, which could get noisy and is a bit of a pain as our normal practice is to issue pull requests against master and not commit directly to it. Maybe if we have a 'heroku-deploy' branch?
* Deploying updates, see ^^

sfoster, 2016-08-23:
We're using my Heroku account for now. The app is 'haiku-status-api'. Flag me here or in email if you want to be added as a collaborator so you can monitor and admin on Heroku

Closed 2016-08-23.

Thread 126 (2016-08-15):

Slot assignments must be symmetrical

sfoster, 2016-08-15:
Per weekly meeting discussion, we want to assume that if friend A is assigned to a slot on friend B's devie, friend B is also assigned to a slot on friend A's device.

We can implement this by simply updating the slots data files for now. But we'll ultimately need to figure out how to enforce and synchronize this.

sfoster, 2016-08-15:
Resolved in #127, 716ee3e6c11401d424e7301ac3cdaebe02528e4a

Closed 2016-08-15.

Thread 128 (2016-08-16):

Handle failed to connect to BLE device in Smart Phone App

punamdahiya, 2016-08-16:
As of now If app is not connected to BLE Device it stays on the Status page, ideally it should force reconnect.

punamdahiya, 2016-08-18:
Updated BLE-Buzzy-Pixel app with disconnect refactor code https://github.com/mozilla/project_haiku.iot/commit/d7ac866d62a9373a70dab6400aa1c1c42473d6c7

Dependent on Issue#93 to implement force reconnect

punamdahiya, 2016-08-23:
Closing as Duplicate of #154

Closed 2016-08-23.

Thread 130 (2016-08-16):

Dynamically assign device name

punamdahiya, 2016-08-16:
Update BLE device sketch to assign device name dynamically e.g. blePeripheral.setDeviceName("BLE-Buzzy-Pixel" +selfLED);

This will help SmartPhone app to identify the correct device to connect to after scanning.

Closed 2016-08-26.

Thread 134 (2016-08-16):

Split out the status server into its own repository

sfoster, 2016-08-16:
At first glance, it looks like it will be a lot easier to deploy our status api server if it exists in its own repository. Currently it is lumped in alongside the arduino stuff, the cordova stuff and various experiments and prototypes

sfoster, 2016-08-16:
New (empty) repo created for this: https://github.com/mozilla/project_haiku_status_api.iot/

sfoster, 2016-08-17:
Move complete in https://github.com/mozilla/project_haiku.iot/commit/f9b125f5468336b6abd45c96e1dbce40ae3f466a

Closed 2016-08-17.

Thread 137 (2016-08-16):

BLENano stop broadcasting after certain time

punamdahiya, 2016-08-16:
I have noticed this intermittent error after ~ 5- 10 minutes of connect to Smart Phone app, BLE device disconnect and reading and setting characteristics on device fails. Peripheral won't
advertise, can't be discovered.

Closing and opening the app fails to find the peripheral device from Buzzy-Pixel app as well as Android nRFConnect.

Pressing reset on BLENano or by unplgging power cable bring BLE device back and shows up in peripheral near by while scanning.

punamdahiya, 2016-08-18:
Error seen in logs after which BLE Nano needs to be reset before connecting

08-17 17:52:34.160 I/chromium(14068): [INFO:CONSOLE(118)] "BLE Buzzy Pixel unexpected disconnect", source: file:///android_asset/www/js/index.js (118)
08-17 17:52:34.161 I/chromium(14068): [INFO:CONSOLE(119)] "{"name":"BLE-Buzzy-Pixel-3","id":"C1:1F:E4:34:A3:D5","advertising":{"CDVType":"ArrayBuffer","data":"AgEGEQZ3rowScZ64vuYRtVSG6RgDEglCTEUtQnV6enktUGl4ZWwtMwAAAAAAAAAAAAAAAAAAAAAAAAAAAAA="},"rssi":-39}", source: file:///android_asset/www/js/index.js (119)

punamdahiya, 2016-08-23:
With plugin updated to Cordova-plugin-bluetoothle , error seen.

Error on write: Unable to write (service: serviceid, characteristics: write charcteristic id)
Error on isDisconnected: Device is disconnected0
Error on IsNotConnected: Device isn't connected0

punamdahiya, 2016-08-23:
Detail Error logs:
08-23 15:10:16.834 I/chromium( 4061): [INFO:CONSOLE(220)] "Encoded stringAQAAAQEAAA==", source: file:///android_asset/www/js/index.js (220)
08-23 15:10:16.843 I/chromium( 4061): [INFO:CONSOLE(220)] "Error on write: Unable to write (service: 0318e986-54b5-11e6-beb8-9e71128cae77, characteristic: 0318ef80-54b5-11e6-beb8-9e71128cae77)", source: file:///android_asset/www/js/index.js (220)
08-23 15:10:17.172 W/bt_btif ( 4416): bta_gattc_conn_cback() - cif=3 connected=0 conn_id=3 reason=0x0008
08-23 15:10:17.172 W/bt_btif ( 4416): bta_gattc_conn_cback() - cif=4 connected=0 conn_id=4 reason=0x0008
08-23 15:10:17.172 W/bt_btif ( 4416): bta_gattc_conn_cback() - cif=6 connected=0 conn_id=6 reason=0x0008
08-23 15:10:17.172 I/bt_btm_sec( 4416): btm_sec_disconnected clearing pending flag handle:64 reason:8
08-23 15:10:17.173 W/bt_l2cap( 4416): L2CA_SetDesireRole() new:x0, disallow_switch:0
08-23 15:10:17.175 D/BtGatt.GattService( 4416): onDisconnected() - clientIf=6, connId=6, address=C1:1F:E4:34:A3:D5
08-23 15:10:17.176 D/BluetoothGatt( 4061): onClientConnectionState() - status=8 clientIf=6 device=C1:1F:E4:34:A3:D5
08-23 15:10:17.179 E/BluetoothRemoteDevices( 4416): state12newState1
08-23 15:10:17.179 D/BluetoothRemoteDevices( 4416): aclStateChangeCallback: sending ACL disconnected intent
08-23 15:10:17.179 D/BluetoothRemoteDevices( 4416): aclStateChangeCallback: State:DisConnected to Device:C1:1F:E4:34:A3:D5
08-23 15:10:17.187 D/BluetoothMapService( 4416): onReceive
08-23 15:10:17.187 D/BluetoothMapService( 4416): onReceive: android.bluetooth.device.action.ACL_DISCONNECTED
08-23 15:10:17.210 V/BluetoothPbapService( 4416): action: android.bluetooth.device.action.ACL_DISCONNECTED
08-23 15:10:17.220 I/chromium( 4061): [INFO:CONSOLE(220)] "Error on isDisconnected: Device is disconnected0", source: file:///android_asset/www/js/index.js (220)
08-23 15:10:22.884 I/Gobi    (  493): vendor/qcom/proprietary/RIDL/RIDLClient/RIDLSQL.cpp:2500: GetTransState() EBADF

punamdahiya, 2016-08-23:
Link to call thats failing https://github.com/mozilla/project_haiku.iot/blob/master/Bluetooth/nRF51822/PhoneGap/BLE-Buzzy-Pixel/www/js/index.js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

punamdahiya, 2016-09-16:
Code branched to https://github.com/mozilla/project_haiku.iot/tree/Haiku_BLE_Beta1, closing as won'tfix

Closed 2016-09-16.

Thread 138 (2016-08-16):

Fix polling with cloud service on app connect

punamdahiya, 2016-08-16:
On app reconnect, toggle polling stops polling causing failure to request status, Update app UI to show polling status and reset polling onConnect of BLE device.

punamdahiya, 2016-08-16:
Merged commit https://github.com/mozilla/project_haiku.iot/commit/05808feef0d9bf3f5300dbde962173e2dee56f8e

Closed 2016-08-16.

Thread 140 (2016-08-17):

Meta - Handle slots in BLEDevice and SmartPhone app

punamdahiya, 2016-08-17:
Handle /user/id/slots to assign slot on a BLE device as shown on TestClient example.html. Cordova app need to be updated to handle slots while read and update of status.

punamdahiya, 2016-09-16:
Code branched to https://github.com/mozilla/project_haiku.iot/tree/Haiku_BLE_Beta1, closing as won'tfix

Closed 2016-09-16.

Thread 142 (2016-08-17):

Add a visual mnemonic to each slot

sfoster, 2016-08-17:
The animals-icon.png was added for this reason, maybe an overlay on the "LED"?

sfoster, 2016-08-17:
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
@KatieCaldwell what do you think? We still have 6 slots for now, so I picked the chicken/rooster for the last

sfoster, 2016-08-18:
Landed in 441e5e7c18c1b072620640d315842f3ba03ee813

Closed 2016-08-18.

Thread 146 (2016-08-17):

Store data in MongoDB

kdsolo, 2016-08-17:
Currently we are using text files to store data. We need to move this to a more formal database like MongoDB to avoid breaking our web API when using Heroku. It will also allow the implementation of access control more easily.

SubhayanDas08, 2021-01-16:
I have done some work on MongoDB and would like to work on this issue.

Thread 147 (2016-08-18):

Delay in setting friend status on BLE device

punamdahiya, 2016-08-18:
As of now the design of polling is to read status from cloud and push on device  every 10 seconds.  This needs to be further optimised so that any update in status is communicated ASAP.

punamdahiya, 2016-09-16:
Code branched to https://github.com/mozilla/project_haiku.iot/tree/Haiku_BLE_Beta1, closing as won'tfix

Closed 2016-09-16.

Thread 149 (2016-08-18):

Hooking up cross-browser audio for the messages

mermi, 2016-08-18:
We need to change the OGG file to MP3 and change the src attribute in <audio> to the alternative <source> , Also call the Buzz function in SlotsAnimation call in client.js

sfoster, 2016-08-18:
Landed in https://github.com/mozilla/project_haiku_status_api.iot/commit/ec7154047faa095571557cd686ff4a917da2125f, thanks!

Closed 2016-08-18.

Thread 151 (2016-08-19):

Play the animation on LED strip

punamdahiya, 2016-08-19:
Play the animation on LED strip

punamdahiya, 2016-09-16:
Code branched to https://github.com/mozilla/project_haiku.iot/tree/Haiku_BLE_Beta1, closing as won'tfix

Closed 2016-09-16.

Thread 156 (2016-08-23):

Indicate which slot sent a rainbow message

sfoster, 2016-08-23:
When more than 1 friend is connected, we currently have no way to know who was the sender when we receive a rainbow.

sfoster, 2016-08-23:
Fixed in https://github.com/mozilla/project_haiku_status_api.iot/commit/266095aacd01305013290039595fb3b44f65a243

Closed 2016-08-23.

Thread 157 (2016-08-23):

Separate data models and client/server logic from display

sfoster, 2016-08-23:
If we enforce a greater separation between all the code that manages state and fetches/pushes data, from the display of that state in the form of the LED colors and animations  - we should be able to re-use large parts of the client code as-is in the Cordova app. And have a better prototype for the device-side implementation.

Maybe something like:
status client < data transport > device view

..where data transport is a bridge to the device/display module which either observes the user models models or can be called explicitly to propagate changes to the display (view). Likewise, input from the device is passed across the bridge to the status client where it can be sent on to the server. In the Cordova app, the bridge speaks Bluetooth GATT characteristics, in our browser clients its just a pass-thru.

sfoster, 2016-09-20:
Closing for now as we're not actively working on the Bluetooth/wearable angle.

Closed 2016-09-20.

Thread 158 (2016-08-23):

Need new script to replace "createUser.js" for Mongo

kdsolo, 2016-08-23:
Build a new script that easily creates and adds new user(s) to the mongo database.

sfoster, 2016-09-20:
Closing for now as we don't currently have this need

Closed 2016-09-20.

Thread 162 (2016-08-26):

Reorganize Bluetooth/nRF51822/Arduino readme

sfoster, 2016-08-26:
The readme we have has explanations for running the examples, but not the actual implementation in BLE-BuzzyPixel.ino. Lets move or remove the example stuff, and make sure this readme has clear step-by-step instructions for getting the necessary code onto the device to try the device.

punamdahiya, 2016-08-29:
Reorganized and updated ReadME https://github.com/mozilla/project_haiku.iot/commit/0bd4e6da1b0751cca543afc0333f3ab0448d3029

Closed 2016-08-29.

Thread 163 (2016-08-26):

Use a real build system for the BLE device

jimporter, 2016-08-26:
The Arduino IDE's build system doesn't seem to give us much in the way of options. There's a project that would let us write a (cross-platform) Makefile to do this, which would give us access to a lot more options, including using C++11.

https://github.com/sudar/Arduino-Makefile

punamdahiya, 2016-09-16:
Code branched to https://github.com/mozilla/project_haiku.iot/tree/Haiku_BLE_Beta1, closing as won'tfix

Closed 2016-09-16.

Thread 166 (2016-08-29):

Make a plan for gathering metrics for September study

sfoster, 2016-08-29:
We'll want to be able to graph user activity  - status changes and messages.
Lets identify what else needs to be logged, and where/how to implement this.

mermi, 2016-08-29:
I have discussed with russ and I knew now what we need to add and to do to integrate the metrics library to our Status API it's easy. But the thing we would discuss is the Key we need to record for Example we need to record the status of each user and the messages sent between them.
and we could make the first scenario of our prototype as we have now : when we start first: all the users icons blink with yellow/green 2- toggle the button to on 3- the status will be changed and we have green light 4- send message (rainbow light) to another online user.

So that's my opinion for that I guess the thing we have to collect is status and messages and we can see the cycle (scenario) in the behavior of our prototype in the future visualizations.

sfoster, 2016-08-30:
That sounds about right to me. Ultimately, just like our earlier user study, we'll want to use the data to read the story. We'll want to be able to determine how often and how frequent users toggle status and send messages, and find patterns in use. We'll draw on the data to inform interview questions to help tease out how the prototypes fit into participant's day-to-day communications and interactions.

@mermi go ahead and file a new issue to start integrating the metrics library into the status server. Please coordinate with @kdsolo if necessary as he knows this code best, and may have changes not yet merged into master. We'll also need to log data from the haiku app to provide context for the server-side logs. We can log charging and battery low events, bluetooth connections/disconnects, as well as possibly loss of network connection (assuming we can send those logs when a connection is next established.) We'll need an issue for that too.

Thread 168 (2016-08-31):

Use explicit stop advertising after successful connect

punamdahiya, 2016-08-31:
Issue #137 where device stop broadcasting still persist intermittently. Handle stop advertising explicitly a) to save battery
b) help resolve issue 137

punamdahiya, 2016-09-15:
WIP commit https://github.com/mozilla/project_haiku.iot/pull/171/commits/cc63896659cb8886ffb596d39277739fd01115b9

punamdahiya, 2016-09-15:
Code branched to https://github.com/mozilla/project_haiku.iot/tree/Haiku_BLE_Beta1, closing as won'tfix

Closed 2016-09-15.

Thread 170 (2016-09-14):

Create a branch of the service before we implemented slots

sfoster, 2016-09-14:
Our initial testing/proof-of-concept of the service didn't have the notion of users and explicit slot assignments. This version was used for the mobile app testing. Lets keep a convenient snapshot of this version in a named branch

sfoster, 2016-09-14:
Created a 'exp4-noslots' branch: https://github.com/mozilla/project_haiku_status_api.iot/tree/exp4-noslots

Closed 2016-09-14.

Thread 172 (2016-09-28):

Emoji Receive Flow - Queued Emojis

punamdahiya, 2016-09-28:
Handle emoji receive flow to display queued emojis

punamdahiya, 2016-09-29:
Updated receive flow to handle queued emojis https://github.com/sfoster/gaia/commit/9ec343b4ba7c9c2be27cda948c23ea631fd47482

Animation to be handled as https://github.com/mozilla/project_haiku.iot/issues/173

Closed 2016-09-29.

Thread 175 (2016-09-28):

Logging - script to get data from cellular logs for text messaging and voice calls

punamdahiya, 2016-09-28:
Logging - log data on sdcard for emoji sent and voice calls

punamdahiya, 2016-10-04:
Cellular logs provides:
Voice Call:
Usage  - (Incoming , Outgoing call)
Contact - (phone number)
Date
Time
Duration - (in hrs mins secs)

Total talk time

In messages:
Usage  - (Incoming Text , Outgoing Text)
Contact - (phone number)
Date
Time

Total texts

punamdahiya, 2016-10-04:
Planning to scrape data from cellular account history web page and save it in a CSV file to render in the format desired

punamdahiya, 2016-10-31:
Tested in prototype. Closing issue

Closed 2016-10-31.

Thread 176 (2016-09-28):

Device power on when plugged in USB

punamdahiya, 2016-09-28:
Device power on when plugged in USB. Workaround is user open box and press power hardware button for five seconds

sfoster, 2016-10-04:
Resolved: WONTFIX
Discussion/options here: https://groups.google.com/forum/#!topic/mozilla.dev.fxos/hyDzNANJjs4
We're not going to implement this for this prototype.

Closed 2016-10-04.

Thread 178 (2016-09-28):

Enclosure to box speaker and z3c

punamdahiya, 2016-09-28:
Enclosure to box speaker and z3c together

sfoster, 2016-10-04:
The source (OpenSCAD) and STL files are in this repo: https://github.com/sfoster/project_haiku_3d.iot/tree/master/experiment-9

Closed 2016-10-04.

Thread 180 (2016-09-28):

Meta - Test send emoji and voice split screen UI flow together

punamdahiya, 2016-09-28:
Test send emoji and voice split screen UI flow together as per spec

punamdahiya, 2016-10-31:
Tested in prototype. Closing issue

Closed 2016-10-31.

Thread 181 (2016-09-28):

Play Audio of ringing for incoming call

punamdahiya, 2016-09-28:
Play Audio of ringing for incoming call up to 6 rings

sfoster, 2016-09-30:
Landed in https://github.com/sfoster/gaia/commit/43a26857cfef771e727a690d9885247601614b23
There's still a bug with the call button not clearing the 'missed' class, I've not tracked that down yet.

sfoster, 2016-09-30:
Fixed what are hopefully last missed/incoming calls bugs in: https://github.com/sfoster/gaia/commit/f5adc7749af075c68c305d480af601ca9667e614

Closed 2016-09-30.

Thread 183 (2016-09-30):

Reboot in landcsape orientation distorts the main screen

punamdahiya, 2016-09-30:
Press of power hardware button for 5 seconds or press of power button on screen bottom right in landscape orientation distorts the main screen after reboot. The issue is intermittent.

Issue is not replicable if the phone is kept horizontal ( e.g. lying on on flat surface) while rebooting.

sfoster, 2016-10-02:
Poking through core.js, I see: https://github.com/mozilla-b2g/gaia/blob/master/apps/system/js/core.js#L61
I've tried adding window.focus() at the top of our app start() method and I /think/ it has done the trick. (but I've other experiments in progress so its possible its something else)

punamdahiya, 2016-10-04:
Merged

Closed 2016-10-04.

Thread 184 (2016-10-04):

Pop up to confirm reboot on tap of power button

punamdahiya, 2016-10-04:
Pop up to confirm reboot on tap of power button

punamdahiya, 2016-10-04:
Three options Reboot , shutdown and Cancel on tap of power button

punamdahiya, 2016-10-04:
Won't fix , opening new issue #186

Closed 2016-10-04.

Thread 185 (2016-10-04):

Add low/no-signal indicator

sfoster, 2016-10-04:
Replace the % in status bar with a graphic/CSS thing that shows: 0 or no signal, low (threshold is say 25%) or good (25+%)

punamdahiya, 2016-10-31:
Tested in prototype. Closing issue

Closed 2016-10-31.

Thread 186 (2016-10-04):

Fix hardware button in system app to power off

punamdahiya, 2016-10-04:
Fix hardware button in system app to power off after device is powered on

sfoster, 2016-10-04:
Landed in https://github.com/sfoster/gaia/commit/adaadc13b24ebd27877271634ab41edb455d228b

Closed 2016-10-04.

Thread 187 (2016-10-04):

Cut off ring tone to 4

punamdahiya, 2016-10-04:
Device should stop ringing after 4 ring tones to avoid reaching voice mail

sfoster, 2016-10-04:
Fixed in https://github.com/sfoster/gaia/commit/687c0d3fef2d19d5dc2f5f983c2a1d05fba9d00d

Closed 2016-10-04.

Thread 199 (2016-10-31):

POC - play audio and data on device

punamdahiya, 2016-10-31:

punamdahiya, 2016-10-31:
Scope of the issue is to play audio received and stored on the device. Received emoji data should be played on the device on receive of play event.

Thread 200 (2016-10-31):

POC - store audio and data on device

punamdahiya, 2016-10-31:
Scope of the issue is to record  audio using microphone and temporarily save on the file system. Selected emojis can be mapped to a data id and stored on device file system before messaging it to paired device

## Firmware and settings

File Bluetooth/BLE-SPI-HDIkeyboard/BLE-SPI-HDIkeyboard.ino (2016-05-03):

/*********************************************************************
 Modified from example nRF51822 based Bluefruit LE modules

 Pick one up today in the adafruit shop!

 Adafruit invests time and resources providing this open source code,
 please support Adafruit and open-source hardware by purchasing
 products from Adafruit!

 MIT license, check LICENSE for more information
 All text above, and the splash screen below must be included in
 any redistribution
*********************************************************************/

/*
  This example shows how to send HID (keyboard/mouse/etc) data via BLE
  Note that not all devices support BLE keyboard! BLE Keyboard != Bluetooth Keyboard
*/

#include <Arduino.h>
#include <SPI.h>
#if not defined (_VARIANT_ARDUINO_DUE_X_) && not defined(ARDUINO_ARCH_SAMD)
  #include <SoftwareSerial.h>
#endif

#include "Adafruit_BLE.h"
#include "Adafruit_BluefruitLE_SPI.h"
#include "Adafruit_BluefruitLE_UART.h"

#include "BluefruitConfig.h"

/*=========================================================================
    APPLICATION SETTINGS

    FACTORYRESET_ENABLE       Perform a factory reset when running this sketch
   
                              Enabling this will put your Bluefruit LE module
                              in a 'known good' state and clear any config
                              data set in previous sketches or projects, so
                              running this at least once is a good idea.
   
                              When deploying your project, however, you will
                              want to disable factory reset by setting this
                              value to 0.  If you are making changes to your
                              Bluefruit LE device via AT commands, and those
                              changes aren't persisting across resets, this
                              is the reason why.  Factory reset will erase
                              the non-volatile memory where config data is
                              stored, setting it back to factory default
                              values.
       
                              Some sketches that require you to bond to a
                              central device (HID mouse, keyboard, etc.)
                              won't work at all with this feature enabled
                              since the factory reset will clear all of the
                              bonding data stored on the chip, meaning the
                              central device won't be able to reconnect.
    MINIMUM_FIRMWARE_VERSION  Minimum firmware version to have some new features
    -----------------------------------------------------------------------*/
    #define FACTORYRESET_ENABLE         0
    #define MINIMUM_FIRMWARE_VERSION    "0.6.6"
/*=========================================================================*/


// Create the bluefruit object, either software serial...uncomment these lines
/*
SoftwareSerial bluefruitSS = SoftwareSerial(BLUEFRUIT_SWUART_TXD_PIN, BLUEFRUIT_SWUART_RXD_PIN);

Adafruit_BluefruitLE_UART ble(bluefruitSS, BLUEFRUIT_UART_MODE_PIN,
                      BLUEFRUIT_UART_CTS_PIN, BLUEFRUIT_UART_RTS_PIN);
*/

/* ...or hardware serial, which does not need the RTS/CTS pins. Uncomment this line */
// Adafruit_BluefruitLE_UART ble(BLUEFRUIT_HWSERIAL_NAME, BLUEFRUIT_UART_MODE_PIN);

/* ...hardware SPI, using SCK/MOSI/MISO hardware SPI pins and then user selected CS/IRQ/RST */
Adafruit_BluefruitLE_SPI ble(BLUEFRUIT_SPI_CS, BLUEFRUIT_SPI_IRQ, BLUEFRUIT_SPI_RST);

/* ...software SPI, using SCK/MOSI/MISO user-defined SPI pins and then user selected CS/IRQ/RST */
//Adafruit_BluefruitLE_SPI ble(BLUEFRUIT_SPI_SCK, BLUEFRUIT_SPI_MISO,
//                             BLUEFRUIT_SPI_MOSI, BLUEFRUIT_SPI_CS,
//                             BLUEFRUIT_SPI_IRQ, BLUEFRUIT_SPI_RST);

// A small helper
void error(const __FlashStringHelper*err) {
  Serial.println(err);
  while (1);
}

/**************************************************************************/
/*!
    @brief  Sets up the HW an the BLE module (this function is called
            automatically on startup)
*/
/**************************************************************************/
void setup(void)
{
  while (!Serial);  // required for Flora & Micro
  delay(500);

  Serial.begin(115200);
  Serial.println(F("Adafruit Bluefruit HID Keyboard Example"));
  Serial.println(F("---------------------------------------"));

  /* Initialise the module */
  Serial.print(F("Initialising the Bluefruit LE module: "));

  if ( !ble.begin(VERBOSE_MODE) )
  {
    error(F("Couldn't find Bluefruit, make sure it's in CoMmanD mode & check wiring?"));
  }
  Serial.println( F("OK!") );

  if ( FACTORYRESET_ENABLE )
  {
    /* Perform a factory reset to make sure everything is in a known state */
    Serial.println(F("Performing a factory reset: "));
    if ( ! ble.factoryReset() ){
      error(F("Couldn't factory reset"));
    }
  }

  /* Disable command echo from Bluefruit */
  ble.echo(false);

  Serial.println("Requesting Bluefruit info:");
  /* Print Bluefruit information */
  ble.info();

  /* Change the device name to make it easier to find */
  Serial.println(F("Setting device name to 'Bluefruit Keyboard': "));
  if (! ble.sendCommandCheckOK(F( "AT+GAPDEVNAME=Bluefruit Keyboard" )) ) {
    error(F("Could not set device name?"));
  }

  /* Enable HID Service */
  Serial.println(F("Enable HID Service (including Keyboard): "));
  if ( ble.isVersionAtLeast(MINIMUM_FIRMWARE_VERSION) )
  {
    if ( !ble.sendCommandCheckOK(F( "AT+BleHIDEn=On" ))) {
      error(F("Could not enable Keyboard"));
    }
  }else
  {
    if (! ble.sendCommandCheckOK(F( "AT+BleKeyboardEn=On"  ))) {
      error(F("Could not enable Keyboard"));
    }
  }

  /* Add or remove service requires a reset */
  Serial.println(F("Performing a SW reset (service changes require a reset): "));
  if (! ble.reset() ) {
    error(F("Couldn't reset??"));
  }

  /* Send AT commands to check power level and change it to 4dbm
     By default powerlevel of BLE SPI Shiedl is set to 0 
     and AT+BLEGETRSSI return 0 if not connected to external device*/
  ble.println("AT+BLEPOWERLEVEL");
  ble.waitForOK();
  ble.println("AT+BLEGETRSSI");
  ble.waitForOK();
  ble.println("AT+BLEPOWERLEVEL=0");
  ble.waitForOK();
  delay(2000);
    
  Serial.println();
  Serial.println(F("Go to your phone's Bluetooth settings to pair your device"));
  Serial.println(F("then open an application that accepts keyboard input"));

  Serial.println();
  Serial.println(F("Enter the character(s) to send:"));
  Serial.println(F("- \\r for Enter"));
  Serial.println(F("- \\n for newline"));
  Serial.println(F("- \\t for tab"));
  Serial.println(F("- \\b for backspace"));

  Serial.println();
}

/**************************************************************************/
/*!
    @brief  Constantly poll for new command or response data
*/
/**************************************************************************/
void loop(void)
{
  // Display prompt
  Serial.print(F("keyboard > "));

  // Check for user input and echo it back if anything was found
  char keys[BUFSIZE+1];
  getUserInput(keys, BUFSIZE);

  Serial.print("\nSending ");
  Serial.println(keys);

  ble.println("AT+BLEGETRSSI");
  ble.waitForOK();
  
  ble.println("AT+BLEPOWERLEVEL");
  ble.waitForOK();
  
  ble.print("AT+BleKeyboard=");
  ble.println(keys);
 

  if( ble.waitForOK() )
  {
    Serial.println( F("OK!") );
  }else
  {
    Serial.println( F("FAILED!") );
  }
}

/**************************************************************************/
/*!
    @brief  Checks for user input (via the Serial Monitor)
*/
/**************************************************************************/
void getUserInput(char buffer[], uint8_t maxSize)
{
  memset(buffer, 0, maxSize);
  while( Serial.available() == 0 ) {
    delay(1);
  }

  uint8_t count=0;

  do
  {
    count += Serial.readBytes(buffer+count, maxSize);
    delay(2);
  } while( (count < maxSize) && !(Serial.available() == 0) );
}

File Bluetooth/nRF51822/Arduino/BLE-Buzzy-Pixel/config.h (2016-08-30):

#ifndef INC_BLEBUZZYPIXEL_CONFIG_H
#define INC_BLEBUZZYPIXEL_CONFIG_H

// This device ID should be unique to help distinguish multiple devices in the
// same area while we're doing prototyping. Just change it to some unique value
// before building.
#define DEVICE_ID "1"

// The UUID for our BLE device. UUIDs can be:
//   16-bit: "ffff"
//  128-bit: "19b10010e8f2537e4f6cd104768a1214" (dashed format also supported)
#define BLE_UUID "0318e986-54b5-11e6-beb8-9e71128cae77"

// The index of the LED representing oneself.
#define SELF_LED 0

// Parameter 1 = number of pixels in strip
// Parameter 2 = Arduino pin number (most are valid)
// Parameter 3 = pixel type flags, add together as needed:
//   NEO_KHZ800  800 KHz bitstream (most NeoPixel products w/WS2812 LEDs)
//   NEO_KHZ400  400 KHz (classic 'v1' (not v2) FLORA pixels, WS2811 drivers)
//   NEO_GRB     Pixels are wired for GRB bitstream (most NeoPixel products)
//   NEO_RGB     Pixels are wired for RGB bitstream (v1 FLORA pixels, not v2)
//   NEO_RGBW    Pixels are wired for RGBW bitstream (NeoPixel RGBW products)

// The number of slots (including the user); each slot has an associated button
// and LED.
#define SLOT_COUNT 7

// The pin connected to the input of the NeoPixels.
#define PIXEL_PIN 5
// The type of NeoPixels, see the NeoPixel strandtest example for more options.
#define PIXEL_TYPE NEO_GRB + NEO_KHZ800

// Define pins (varies per shield/board).
#define BLE_REQ 10
#define BLE_RDY 2
#define BLE_RST 9

// Button pin.
#define BUTTON_PIN  6

#endif

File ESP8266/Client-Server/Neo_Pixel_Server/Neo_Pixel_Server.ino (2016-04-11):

#include <ESP8266WiFi.h>
#include <Adafruit_NeoPixel.h>

// Parameter 1 = number of pixels in strip
// Parameter 2 = Arduino pin number (most are valid)
// Parameter 3 = pixel type flags, add together as needed:
//   NEO_KHZ800  800 KHz bitstream (most NeoPixel products w/WS2812 LEDs)
//   NEO_KHZ400  400 KHz (classic 'v1' (not v2) FLORA pixels, WS2811 drivers)
//   NEO_GRB     Pixels are wired for GRB bitstream (most NeoPixel products)
//   NEO_RGB     Pixels are wired for RGB bitstream (v1 FLORA pixels, not v2)
//   NEO_RGBW    Pixels are wired for RGBW bitstream (NeoPixel RGBW products)

#define PIXEL_COUNT 60    // The number of NeoPixels connected to the board.

#define PIXEL_PIN   4     // The pin connected to the input of the NeoPixels.

#define PIXEL_TYPE  NEO_GRB + NEO_KHZ800  // The type of NeoPixels, see the NeoPixel
                                          // strandtest example for more options.

// Create NeoPixel strip from above parameters.
Adafruit_NeoPixel strip = Adafruit_NeoPixel(PIXEL_COUNT, PIXEL_PIN, PIXEL_TYPE);                                 

//////////////////////
// WiFi Definitions //
//////////////////////
const char WiFiAPPSK[] = "sparkfun";

/////////////////////
// Pin Definitions //
/////////////////////
const int LED_PIN = 5; // Thing's onboard, green LED
const int ANALOG_PIN = A0; // The only analog pin on the Thing
const int DIGITAL_PIN = 12; // Digital pin to be read

WiFiServer server(80);

void setup() 
{
  initHardware();  
  setupWiFi();
  server.begin();
  // Initialize NeoPixels.
  strip.begin();
  strip.show();
}

void animatePixels(Adafruit_NeoPixel& strip, uint8_t r, uint8_t g, uint8_t b, int periodMS) {
  // Animate the NeoPixels with a simple theater chase/marquee animation.
  // Must provide a NeoPixel object, a color, and a period (in milliseconds) that controls how
  // long an animation frame will last.
  // First determine if it's an odd or even period.
  int mode = millis()/periodMS % 2;
  // Now light all the pixels and set odd and even pixels to different colors.
  // By alternating the odd/even pixel colors they'll appear to march along the strip.
  for (int i = 0; i < strip.numPixels(); ++i) {
    if (i%2 == mode) {
      strip.setPixelColor(i, r, g, b);  // Full bright color.
    }
    else {
      strip.setPixelColor(i, r/4, g/4, b/4);  // Quarter intensity color.
    }
  }
  strip.show();
}

void loop() 
{
  // Check if a client has connected
  WiFiClient client = server.available();
  if (!client) {
    return;
  }

  // Read the first line of the request
  String req = client.readStringUntil('\r');
  Serial.println(req);
  client.flush();
  
  // Match the request
  int val = -1; // We'll use 'val' to keep track of both the
                // request type (read/set) and value if set.
  if (req.indexOf("/led/0") != -1)
    val = 0; // Will write LED low
  else if (req.indexOf("/led/1") != -1)
    val = 1; // Will write LED high
  else if (req.indexOf("/read") != -1)
    val = -2; // Will print pin reads
  // Otherwise request will be invalid. We'll say as much in HTML

  // Set GPIO5 and neopixel according to the request
  if (val >= 0) {
    digitalWrite(LED_PIN, val);
    // Animate pixels.
   if (val == 0) {
      // Turn neo pixel purple #DF0AFF and animate
      animatePixels(strip, 223, 10, 255, 300);
    }
    else {
      // Reset back to black
      animatePixels(strip, 0, 0, 0, 300);
    }
  }
  
  client.flush();

  // Prepare the response. Start with the common header:
  String s = "HTTP/1.1 200 OK\r\n";
  s += "Content-Type: text/html\r\n\r\n";
  s += "<!DOCTYPE HTML>\r\n<html>\r\n";
  // If we're setting the LED, print out a message saying we did
  if (val >= 0)
  {
    s += "LED is now ";
    s += (val)?"high":"low";
  }
  else if (val == -2)
  { // If we're reading pins, print out those values:
    s += "Analog Pin = ";
    s += String(analogRead(ANALOG_PIN));
    s += "<br>"; // Go to the next line.
    s += "Digital Pin 12 = ";
    s += String(digitalRead(DIGITAL_PIN));
  }
  else
  {
    s += "Invalid Request.<br> Try /led/1, /led/0, or /read.";
  }
  s += "</html>\n";

  // Send the response to the client
  client.print(s);
  delay(1);
  Serial.println("Client disonnected");

  // The client will actually be disconnected 
  // when the function returns and 'client' object is detroyed
}

void setupWiFi()
{
  WiFi.mode(WIFI_AP);
  
  // Do a little work to get a unique-ish name. Append the
  // last two bytes of the MAC (HEX'd) to "Thing-":
  uint8_t mac[WL_MAC_ADDR_LENGTH];
  WiFi.softAPmacAddress(mac);
  String macID = String(mac[WL_MAC_ADDR_LENGTH - 2], HEX) +
                 String(mac[WL_MAC_ADDR_LENGTH - 1], HEX);
  macID.toUpperCase();
  String AP_NameString = "ESP8266";// + macID;
  
  char AP_NameChar[AP_NameString.length() + 1];
  memset(AP_NameChar, AP_NameString.length() + 1, 0);
  
  for (int i=0; i<AP_NameString.length(); i++)
    AP_NameChar[i] = AP_NameString.charAt(i);
  
  WiFi.softAP(AP_NameChar, WiFiAPPSK);
}

void initHardware()
{
  Serial.begin(115200);
  pinMode(DIGITAL_PIN, INPUT_PULLUP);
  pinMode(LED_PIN, OUTPUT);
  digitalWrite(LED_PIN, LOW);
}

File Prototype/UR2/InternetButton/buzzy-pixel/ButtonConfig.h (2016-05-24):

// EVENT NAME SETTINGS
// ----------------------------------------------------------------------------------------------
// These settings are used in both pair of buttons
// ----------------------------------------------------------------------------------------------

// Comment before flashing Device_2
// For DEVICE_1
#define PUBLISH_EVENT_NAME "DEVICE_1_BUTTON_PRESS"
#define SUBSCRIBE_EVENT_NAME  "DEVICE_2_BUTTON_PRESS"


// Uncomment before flashing Device_2
// For DEVICE_2
//#define PUBLISH_EVENT_NAME "DEVICE_2_BUTTON_PRESS"
//#define SUBSCRIBE_EVENT_NAME  "DEVICE_1_BUTTON_PRESS"

// Event to confirm handshake
#define PUBLISH_CONFIRM_EVENT "RECEIVED_CONFIRMATION"

#define VERBOSE_MODE  true  // If set to 'true' enables debug output
#define BATTERY_CHECK_TIME 1800000 // Check after every 1800 seconds or 30 mins
#define BATTERY_THRESHOLD 3 // Battery threshold below which device should sleep
#define BATTERY_CHECK 1
#define BATTERY_LEVEL_EVENT "BATTERY_LEVEL"

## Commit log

2016-03-28 ESP8266 switch client commit
2016-04-11 Client-Server example sketch using VCNL4010 proximity sensor and NeoPixel ambient indicator
2016-05-03 Example sketches using HC-05 and BLE SPI bluetooth modules
2016-05-04 [Prototype-UR#2][Issue-#3]-Respond to messages from paired device
    [ButtonConfig.h, buzzy-pixel.ino]
2016-05-04 Rename folder Prototype-UR#2
2016-05-04 Fix of delay in response on button click
    [buzzy-pixel.ino]
2016-05-05 Hook up neopixels, vibration motor and button to bare Photon board
    [BlingButton.cpp, buzzy-neopixel.ino]
2016-05-05 Issue #1 - Fix for connecting to Wifi through browser
    [buzzy-pixel.ino]
2016-05-05 Simple convenience script to flash a device using the particle CLI
2016-05-06 Issue #2 - Use and update BlingButton lib with multiple button clicks event handling
    [BlingButton.cpp, buzzy-pixel.ino]
2016-05-09 Issue #8, #9, #11 - Implement message LED animations
    [BlingButton.cpp, buzzy-pixel.ino]
2016-05-09 Initial README, with Bill of Materials
2016-05-16 Hinge module (w/o integral pin) first pass
    [pin-hinge.scad]
2016-05-16 WIP enclosure, tighten up hinge and its example model
    [enclosure.scad, pin-hinge.scad, test-hinge.scad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]
2016-05-17 Add strap to enclosure base
    [enclosure.scad, pin-hinge.scad]
2016-05-17 Reworking enclosure shell w. LED strip channel
    [enclosure.scad]
2016-05-17 Issue #24 - Put device to deep sleep if battery level is low
    [BlingButton.cpp, ButtonConfig.h, buzzy-pixel.ino]
2016-05-18 Tweak and adjustments
    [enclosure.scad, pin-hinge.scad]
2016-05-19 Add access to battery connector, rework straps
    [enclosure.scad]
2016-05-19 Fix strap/retainer. Add version imprint to base
    [enclosure.scad]
2016-05-19 Log battery voltage on click in the Photon (scratch) code
2016-05-23 Issue#24 - Update battery check code to use a config flag
    [BlingButton.cpp, ButtonConfig.h, buzzy-pixel.ino]
2016-05-23 Issue#24 - Check if battery flag is defined
    [ButtonConfig.h, buzzy-pixel.ino]
2016-05-23 Issue#24 Log battery level
    [BlingButton.cpp, ButtonConfig.h, buzzy-pixel.ino]
2016-05-24 Calculator to see value from battery through voltage divider, adc and back again
2016-05-24 Issue #24 - Put device to sleep below battery threshold
    [ButtonConfig.h, buzzy-pixel.ino]
2016-05-26 Rename Prototype-UR2 folder to Prototype
    [enclosure.scad, pin-hinge.scad, test-hinge.scad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]
2016-06-02 WIP Fritzing file w. schematic and eventually/hopefully breadboard wiring diagram
    [BlinkyButton.fzz]
2016-06-02 Move Fritzing file to correct assets folder
    [BlinkyButton.fzz]
2016-06-03 Issue 18: Wiring diagram & BOM
    [BlinkyButton.fzz]
2016-06-03 Fixup: correct button pullup resistor
    [BlinkyButton.fzz]
2016-06-03 Add print-ready STL for the enclosure; new README section for building the prototype
    [enclosure.stl]
2016-06-07 Update Prototype ReadMe
2016-06-07 Add context and contact prompt to Prototype README
2016-07-22 Update ReadMe with BOM
2016-07-22 Improved visualization, showing LEDs on wrist
2016-07-22 Make start/stop buttons a single togglebutton
2016-07-26 Set status by pressing first/home LED
2016-07-27 BLE circuit board images
2016-07-27 Rename circuit images path
2016-08-02 add the post request to change status and blink the Led
2016-08-03 Issue 50 - Key-framed color animations
    Color sample at each frame to animate across the strip of LEDs
    Add standard penner easing functions, parameterize easing
    Added RGB to HSV implementation and vice-versa
    Add a HSV color animation example
2016-08-03 Issue 79 -Mark and highlight the 'self' slot
2016-08-03 Switch to using divs not canvas for LED/slots
2016-08-05 Add missing LED slots+styling, fix isSelf logic, guard against newlines in data file
2016-08-09 Issue#61 - Implement get and post request from cordova app
    [BLE-Buzzy-Pixel.ino]
2016-08-09 slots api
2016-08-12 Rework animations for playing on state change
    * Whole-strip and individual pixel animations, some state/animationStack issue in/from onStatusChange
    * Move out the Device stuff into a SlotsAnimationManager
    * Get the color curve plotting working again
    * Get some of the animation demos working again
    * Update the animations page
    * Fix initial slot state as -1. Add test buttons for status changes and getting rainbow messages
2016-08-13 new client.js with slots implemented
2016-08-13 slots API with promises
2016-08-13 Refactor of the async init code. We only need to fetch slot assignments once
2016-08-13 Implement slot state animations into client.js
2016-08-15 Hook up rainbow sending and receiving in the client
    Send of message with local animation on slot
    Poll for messages, play new messages
2016-08-15 New slot assignments: 0 knows everyone; 1,2,3 know each other; 4 and 5 know each other and 6 only knows 0
2016-08-22 Move Arduino example sketches to Examples folder
2016-08-25 Create config.h to hold device-specific config values
2016-08-25 Add a unique device ID in config.h
    This is used to provide unique friendly names for devices in the same area
    during the prototyping phase. Since the Arduino IDE's build system is
    painfully simplistic, just change the value in config.h directly before
    building.
2016-08-29 Add ReadMe for BLE-Buzzy-Pixel Arduino sketch
2016-08-29 Clean up the Buzzy Pixel code
    [BLE-Buzzy-Pixel.ino, config.h]
2016-09-21 Move UR2 prototype under UR2 folder
    [BlinkyButton.fzz, enclosure.scad, enclosure.stl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]
2016-09-21 Call Button android native app
2016-10-10 data scraper
    [650-960-5390_Total Usage - Voice, Text, Data_10-4-2016_10-10-2016.pdf.csv, exampleCSV.csv]
2016-10-10 Removing input data files
    [650-960-5390_Total Usage - Voice, Text, Data_10-4-2016_10-10-2016.pdf.csv]
2016-10-11 Add lookup, to map numbers to device ids. Add datetime field. Send output to stdout
2016-10-12 Strip phone numbers from filename and data; sample output
